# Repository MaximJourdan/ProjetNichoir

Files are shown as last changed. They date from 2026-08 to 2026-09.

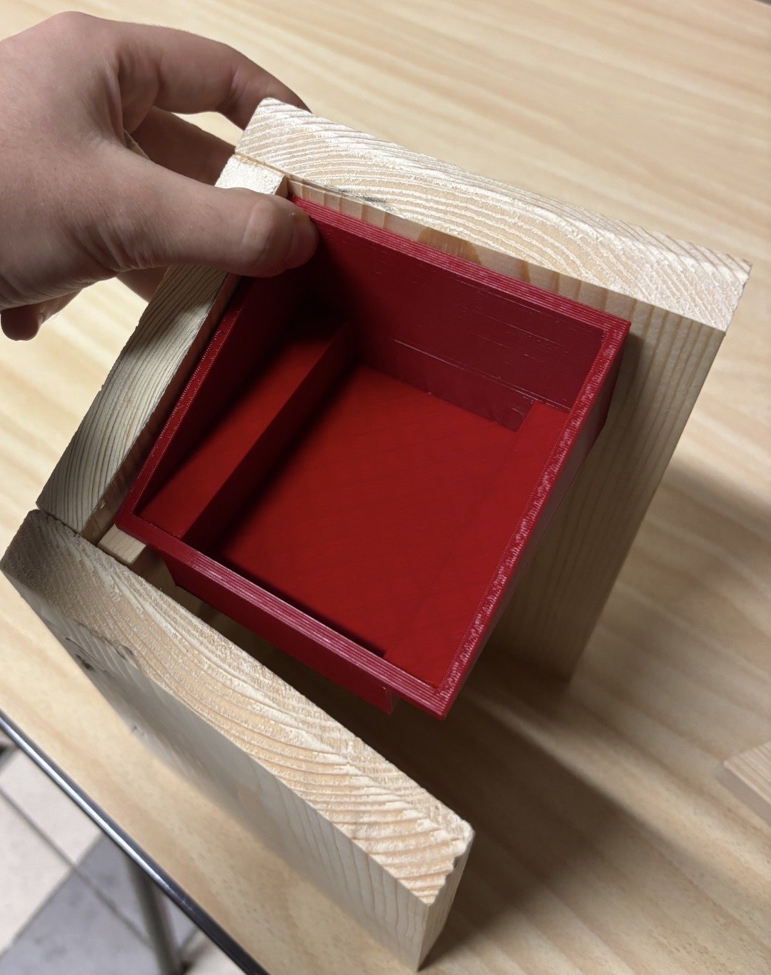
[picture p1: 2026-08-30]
ImagesEtSchemas/Nichoir4.jpg

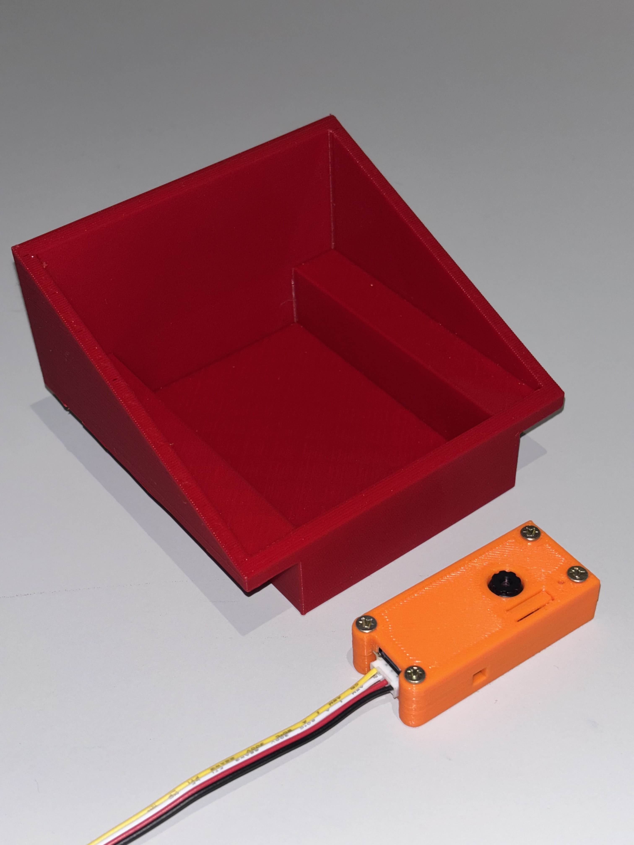
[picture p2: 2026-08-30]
ImagesEtSchemas/Nichoir2.jpg

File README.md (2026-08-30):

# 🐦 Nichoir Connecté – SmartCities 2025-2026

Projet étudiant développé à la **Haute École de la Province de Liège (HEPL)** dans le cadre du programme **Sciences de l’ingénieur industriel – orientation informatique**.

## 📌 Objectif
Créer un nichoir intelligent et connecté permettant de suivre la vie des oiseaux :
- Coût accessible (moins de 50 €)
- Autonomie énergétique prolongée (6 mois à 1 an sur batterie)
- Évolutif : ajout possible d’un panneau solaire

---

## 🔎 Analyse du marché
- Prix des solutions existantes : 130 – 300 €
- Alimentation : câble, panneaux solaires
- Stockage : carte SD, Wi-Fi cloud privé, RTSP
- Exemples : Green Backyard, Greenfeathers Bird Box Camera Kit

---

## ⚙️ Caractéristiques techniques
- **Microcontrôleur** : ESP32-DOWDQ6-V3  
- **Mémoire** : 8 MB PSRAM  
- **Caméra** : OV3660, 3MP, DFOV 66.5°, résolution max 2048x1536  
- **Indicateurs** : LED de statut + bouton RESET  
- **Gestion énergie** : RTC BM8563, consommation en veille ~2 µA, connecteur batterie externe  
- **Connectivité** : Wi-Fi, port USB debug, port HY2.0-4P pour périphériques externes  

Librairies utilisées : [TimerCam Arduino](https://github.com/m5stack/TimerCam-arduino/tree/master)

---

## 🔋 Gestion de l’énergie
- Mode **standby** : réveil quotidien pour envoi du niveau de batterie via MQTT  
- Mode **présence** : détection PIR → capture photo + envoi batterie associé  

---

## 📡 Fonctionnement du système
### Détection de mouvement
- Capteur PIR → déclenche capture photo avec éclairage IR

### Transmission des données
- Envoi des images au Raspberry Pi via Wi-Fi
- Script Python MQTT listener → stockage dans MariaDB
- Serveur Flask → galerie web + affichage des données

---

## 🛠️ Conception
- Breakout pour PIR, LED, TimerCam
- Package complet avec batterie/support piles
- Versioning et suivi sur GitHub

---

## ✅ Évaluation & Compétences
### C1 – Concevoir des systèmes complexes
- Architecture claire et modulaire
- Passage de la conception théorique à la réalisation pratique
- Optimisation en fonction des tests

### C2 – Mettre en œuvre des systèmes complexes
- Fiabilité et traçabilité des tests
- Documentation et reproductibilité
- Respect du cahier des charges

### C3 – Développer sa professionnalité
- Auto-formation et apprentissage continu
- Initiative et autonomie dans la recherche de solutions

---

## 🚀 Installation & Utilisation
### Prérequis
- ESP32 TimerCam
- Raspberry Pi avec Python 3
- MariaDB/MySQL
- Flask

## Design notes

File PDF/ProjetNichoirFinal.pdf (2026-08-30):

# Projet Nichoir

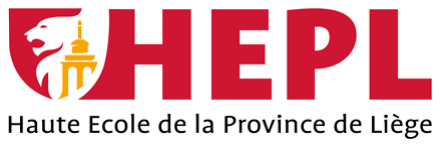
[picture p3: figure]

Travail Réalisé par Jourdan Maxim et Monthe Modeste

Année 2025-2026 Passerelle Électronique M13P

Introduction | 4
Cahier des Charges | 4
Objectifs généraux | 4
Exigences fonctionnelles | 5
Schéma | 5
Serveur MQTT Raspberry PI | 6
Pourquoi le protocole MQTT | 6
Mise en place du serveur MQTT sur Raspberry Pi | 6
Organisation des échanges MQTT | 6
Transmission des images par fragmentation | 6
Application Flask | 7
Architecture de l’application | 7
Fonctionnement général | 7
Interface Web | 8
Extensibilité du système | 8
M5 STACK Esp32 Camera | 8
Accès Wi-Fi et point d’accès de configuration | 9
Détection de mouvement et déclenchement des captures | 9
Transmission des données vers le serveur | 10
Gestion de l’énergie et modes de veille | 10
Capteur Infrarouge PIR | 10
Principe de fonctionnement | 10
Description des connexions du module PIR | 11
GND (Ground) | 12
3.3 V (Alimentation) | 12
Photoresist (Entrée photorésistance) | 12
Potentiomètre de sensibilité (Pot Sensi) | 12
Potentiomètre de temporisation (Pot Time) | 12
OUT (Sortie numérique) | 13
Board 5v PIR | 13
Schéma | 14
Alimentation et conversion de tension | 14
Conditionnement du capteur PIR | 15
Intégration de la LED d’éclairage | 15
Interface avec le module ESP32 TimerCAM | 16
Intérêt de la board dédiée | 16

Dessin 3D | 16
Étapes de conception et apprentissage | 17
Logiciel utilisé et méthodologie | 18
Fonctionnalité et sécurité thermique | 19
Résultat | 19
Tests | 19
Test du capteur PIR | 20
Transmission des images via MQTT | 20
Autonomie énergétique | 20
Limites | 20
Réveil depuis le mode veille du PIR | 20
Transmission réseau dépendante de la stabilité Wi-Fi | 21
Autonomie réelle vs autonomie théorique | 21
Exposition aux éléments | 21
Conclusion | 21
Perspectives | 22
Intégration d’un réseau LoRa Mesh | 22
Alimentation solaire | 22
Optimisation du mode veille | 22
Extension des fonctionnalités | 23
Scalabilité et modularité | 23

## Introduction

Le développement des villes intelligentes SmartCities s’accompagne d’un intérêt croissant pour le suivi de l’environnement urbain et de la biodiversité. La faune, et en particulier les oiseaux, constitue un indicateur pertinent de la qualité écologique des milieux urbains. Le suivi de leur comportement et de leur présence permet d’apporter des informations utiles tant pour la recherche scientifique que pour la sensibilisation du public à la préservation de l’environnement.

Dans ce contexte, le projet de nichoir connecté, réalisé dans le cadre du cours de passerelle Smart Cities, s’inscrit dans une démarche de conception d’un système IoT autonome, communicant et à faible consommation énergétique. L’objectif principal est de concevoir un nichoir intelligent capable de détecter la présence d’oiseaux, de capturer des images de manière non-intrusive et de transmettre ces données vers une infrastructure distante pour leur stockage et leur visualisation.

Le projet vise à proposer une solution économiquement accessible, avec un coût de fabrication inférieur aux solutions existantes du marché, tout en garantissant une autonomie énergétique prolongée grâce à l’utilisation d’une batterie et à une gestion optimisée de la consommation. L’ensemble du système repose sur un microcontrôleur embarqué intégrant une caméra, un capteur de mouvement infrarouge passif (PIR), ainsi qu’une communication Wi-Fi vers un serveur distant basé sur un Raspberry Pi.

Ce rapport présente l’ensemble des étapes de conception, de réalisation et de validation du nichoir connecté. Il aborde successivement l’architecture globale du système, les choix technologiques, la gestion de l’énergie, l’infrastructure de communication et de traitement des données, ainsi que les tests réalisés. Enfin, les limites du système actuel et les perspectives d’amélioration sont discutées.

## Cahier des Charges

## Objectifs généraux

Le système doit permettre :
La surveillance de l’activité à l’intérieur d’un nichoir à l’aide d’un système de détection de mouvement.
La capture d’images lors de la détection d’une présence.
La transmission des données vers un serveur distant pour stockage et visualisation.

Une autonomie énergétique prolongée, compatible avec une utilisation sur plusieurs mois sans intervention humaine.
Un coût global réduit, adapté à une solution pédagogique et déployable à grande échelle.

## Exigences fonctionnelles

Système embarqué:
Utilisation d’un module M5Stack ESP32 Camera (TimerCam).
Détection de mouvement à l’aide d’un capteur infrarouge passif (PIR).
Capture d’images déclenchée par le capteur PIR.
Éclairage infrarouge (LED IR) lors de la prise de vue afin de limiter l’impact sur les oiseaux.
Gestion des modes veille (sleep) afin de réduire la consommation énergétique.

Connectivité:
Mise en place d’un point d’accès Wi-Fi permettant la configuration initiale du réseau. Connexion automatique au réseau Wi-Fi configuré.
Transmission des images et des données via le protocole MQTT.

## Schéma

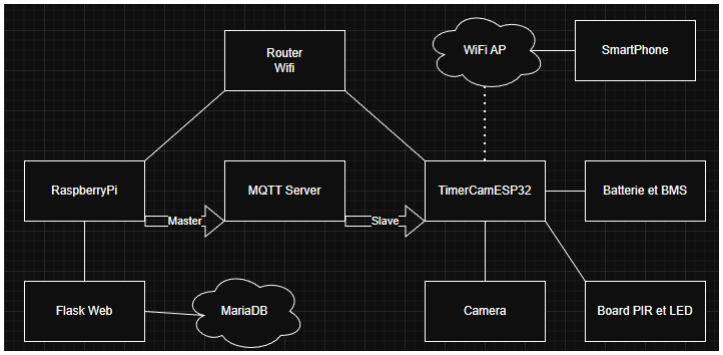
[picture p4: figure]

## Serveur MQTT Raspberry PI

## Pourquoi le protocole MQTT

Le protocole MQTT (Message Queuing Telemetry Transport) a été retenu pour sa légèreté et sa faible consommation réseau, adaptées aux systèmes IoT alimentés sur batterie. Son modèle publish/subscribe permet une communication asynchrone efficace, contrairement à HTTP, plus coûteux en ressources. MQTT facilite également l’évolutivité du système, plusieurs services pouvant exploiter les mêmes données sans modifier le module embarqué.

## Mise en place du serveur MQTT sur Raspberry Pi

Un Raspberry Pi est utilisé comme serveur central hébergeant le broker MQTT Mosquitto. Il assure la réception des images et des métadonnées envoyées par l’ESP32, ainsi que leur redistribution vers les services applicatifs. La configuration du broker permet la réception de messages volumineux nécessaires à la transmission des images.

## Organisation des échanges MQTT

Les échanges sont structurés à l’aide de topics MQTT distincts, séparant les images, les métadonnées (horodatage, niveau de batterie) et les informations de diagnostic. Cette organisation facilite le traitement et l’exploitation des données par le serveur applicatif.

## Transmission des images par fragmentation

Les images étant trop volumineuses pour un envoi unique, elles sont fragmentées en plusieurs blocs transmis successivement via MQTT. Un message de fin permet la reconstitution de l’image côté serveur, garantissant une transmission fiable tout en respectant les contraintes du protocole.

Dans une version future du système, des mécanismes de sécurisation des échanges MQTT (authentification, chiffrement TLS) pourraient être intégrés afin d’améliorer la protection des données transmises.

L’ensemble des scripts et commandes est disponible sur le dépôt GitHub du projet.

## Application Flask

Afin de permettre la visualisation des données collectées par le nichoir connecté, une application Web a été développée à l’aide du framework Flask, exécutée sur le Raspberry Pi. Flask a été choisi pour sa légèreté, sa simplicité d’intégration avec Python et sa pertinence dans des projets IoT de petite à moyenne échelle.

L’application Flask joue le rôle d’interface entre la base de données et l’utilisateur final. Elle permet de consulter les images capturées par le module ESP32 TimerCAM ainsi que les métadonnées associées, telles que la date de capture et le niveau de batterie du système embarqué.

## Architecture de l’application

L’application Web est intégrée dans un script unifié exécuté sur le Raspberry Pi, combinant :
- un listener MQTT chargé de recevoir les images et les métadonnées,
- une base de données MariaDB assurant le stockage persistant,
- un serveur Web Flask permettant l’affichage et l’accès aux données.

Cette architecture permet un fonctionnement continu et autonome du système, tout en limitant le nombre de services à gérer sur le Raspberry Pi.

## Fonctionnement général

Lorsqu’une image est reçue via le protocole MQTT, celle-ci est sauvegardée sur le système de fichiers du Raspberry Pi. Le chemin de l’image ainsi que les informations associées sont ensuite enregistrés dans la base de données. L’application Flask interroge cette base afin de récupérer l’ensemble des captures disponibles et de les présenter à l’utilisateur via une interface Web.

La page principale de l’application affiche une galerie d’images, organisée par ordre chronologique inverse. Chaque capture est accompagnée de métadonnées permettant d’évaluer l’état du système au moment de la prise de vue, notamment le niveau de batterie.

## Interface Web

L’interface Web a été conçue afin d’être claire, responsive et facilement exploitable sur différents supports. Elle propose :
- une galerie d’images issue des captures du nichoir,
- des indicateurs synthétiques tels que le nombre total de captures et le niveau de batterie moyen,
- une mise en forme facilitant l’analyse visuelle des données collectées.
Un mécanisme de rafraîchissement périodique permet d’actualiser automatiquement l’affichage, assurant ainsi la consultation des nouvelles images sans intervention manuelle.

## Extensibilité du système

En complément de l’interface graphique, l’application Flask expose des routes dédiées permettant d’accéder aux données sous forme structurée. Cette approche rend le système évolutif et compatible avec de futures extensions, telles que l’intégration d’outils d’analyse, de supervision ou de visualisation avancée.

Ainsi, l’application Flask constitue un élément central du projet, transformant le Raspberry Pi en un serveur Web complet, capable de valoriser les données issues du nichoir connecté de manière efficace et accessible.

## M5 STACK Esp32 Camera

Le système embarqué du nichoir repose sur un module M5Stack ESP32 TimerCAM, intégrant un microcontrôleur ESP32, une caméra et une gestion native de l’alimentation sur batterie. Ce module a été choisi pour sa compacité, sa faible consommation énergétique et sa capacité à combiner acquisition d’images et connectivité Wi-Fi au sein d’un même dispositif.

L’ESP32 TimerCAM constitue le cœur du système IoT. Il assure la détection d’événements à l’intérieur du nichoir, la capture des images, ainsi que leur transmission vers le serveur distant hébergé sur Raspberry Pi.

## Accès Wi-Fi et point d’accès de configuration

Afin de faciliter le déploiement du nichoir dans différents environnements, un
mécanisme de configuration réseau dynamique a été mis en place. Lors du premier démarrage, ou en l’absence de réseau connu, le module ESP32 crée automatiquement un point d’accès Wi-Fi dédié.

Ce point d’accès permet à l’utilisateur de se connecter au module et de configurer les identifiants du réseau Wi-Fi local sans avoir à modifier le code embarqué. Une fois les paramètres enregistrés, l’ESP32 se connecte automatiquement au réseau configuré lors des démarrages suivants.

Cette approche améliore la flexibilité du système et rend son installation accessible, même sans compétences avancées en programmation embarquée.

## Détection de mouvement et déclenchement des captures

La détection de présence à l’intérieur du nichoir est réalisée à l’aide d’un capteur infrarouge passif (PIR). Lorsqu’un mouvement est détecté, le capteur déclenche une séquence d’actions automatisées.

Dans un premier temps, une LED est activée afin d’éclairer brièvement la scène, garantissant une qualité d’image suffisante même dans des conditions de faible luminosité. La caméra capture ensuite une image de l’intérieur du nichoir.

Une fois la capture effectuée, l’image est immédiatement préparée pour être transmise vers le serveur distant. Ce fonctionnement événementiel permet de limiter les captures inutiles et de réduire la consommation énergétique globale du système.

En complément, des captures périodiques sont également réalisées à intervalles réguliers afin d’assurer un suivi continu de l’activité, même en l’absence de détection de mouvement.

## Transmission des données vers le serveur

Après chaque capture, l’image ainsi que les métadonnées associées (horodatage, niveau de batterie, identifiant du dispositif) sont envoyées via le réseau Wi-Fi en utilisant le protocole MQTT.

En raison des contraintes mémoire du microcontrôleur et de la taille des images, celles-ci sont fragmentées en plusieurs blocs avant d’être transmises. Le serveur reconstitue ensuite l’image complète à la réception de l’ensemble des fragments. Cette méthode garantit une transmission fiable tout en respectant les limitations matérielles de l’ESP32.

## Gestion de l’énergie et modes de veille

L’autonomie énergétique constitue un enjeu majeur du projet. Le module ESP32 TimerCAM fonctionne sur batterie et intègre plusieurs mécanismes visant à réduire sa consommation.

Des phases de mise en veille sont utilisées entre les captures afin de limiter l’activité du microcontrôleur. Des tests ont été réalisés avec différents modes de veille, notamment le deep sleep, afin d’évaluer leur compatibilité avec la détection de mouvement via le capteur PIR.

Ces expérimentations ont mis en évidence certaines limitations, notamment la difficulté de réveiller de manière fiable le système depuis un état de veille profonde à l’aide du capteur PIR. Ces contraintes ont conduit à des compromis entre autonomie énergétique et fiabilité de la détection, qui sont discutés plus en détail dans la section dédiée aux limites du système.

## Capteur Infrarouge PIR

## Principe de fonctionnement

Le capteur infrarouge passif (PIR – Passive Infrared Sensor) est utilisé pour détecter la présence ou le mouvement d’un corps chaud dans son champ de vision. Il fonctionne en mesurant les variations du rayonnement infrarouge émis naturellement par les objets, et en particulier par les êtres vivants.

Le capteur PIR ne génère pas de rayonnement ; il se contente de détecter les variations d’énergie infrarouge reçues. Lorsqu’un oiseau entre dans le nichoir ou se déplace à proximité du capteur, la variation thermique est détectée et convertie en un signal électrique exploitable par le microcontrôleur.

Ce type de capteur présente plusieurs avantages pour un système autonome :
- faible consommation énergétique
- fonctionnement simple
- absence d’émission active, donc non-intrusif pour les animaux

Ces caractéristiques en font un choix particulièrement adapté au projet de nichoir connecté.

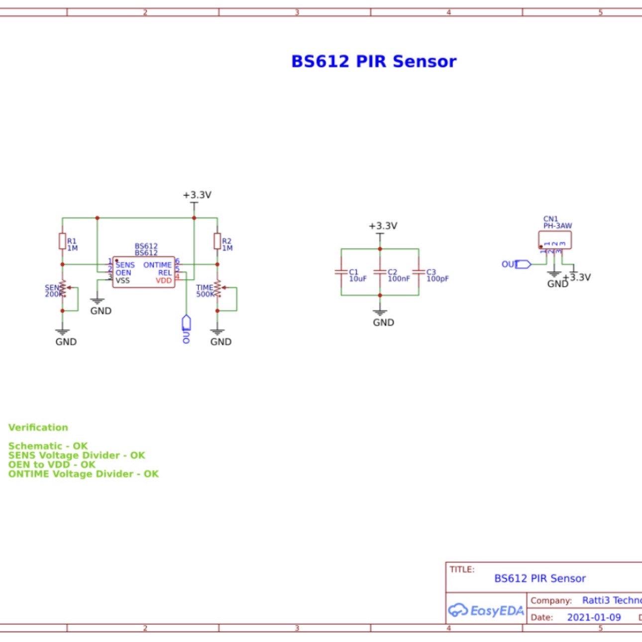
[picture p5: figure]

## Description des connexions du module PIR

Le module PIR utilisé dans ce projet dispose de six connexions, permettant d’alimenter le capteur, de régler son comportement et de récupérer le signal de détection.

GND (Ground)
La broche GND correspond à la masse du circuit. Elle est reliée à la masse commune du système afin d’assurer une référence électrique stable entre le capteur PIR et le microcontrôleur ESP32.

### 3.3 V (Alimentation)

La broche 3.3 V permet d’alimenter le module PIR. Dans ce projet, le capteur est alimenté par la tension fournie par le système embarqué. L’utilisation d’une tension compatible avec l’ESP32 évite l’ajout de composants de conversion supplémentaires.

Photoresist (Entrée photorésistance)
La broche photoresist est associée à une photorésistance intégrée au module. Elle permet d’adapter le comportement du capteur en fonction de la luminosité ambiante.

Cette entrée peut être utilisée pour inhiber la détection lorsque la lumière est suffisante, ou au contraire pour privilégier les détections en conditions de faible luminosité. Dans le cadre du projet, cette fonctionnalité a été identifiée comme une possibilité d’amélioration, mais n’a pas été exploitée pleinement.

Potentiomètre de sensibilité (Pot Sensi)
Le potentiomètre de sensibilité permet de régler la distance ou l’amplitude de détection du capteur PIR. Un réglage élevé augmente la portée du capteur, tandis qu’un réglage plus faible limite la zone de détection.

Ce paramètre est important afin d’éviter les déclenchements intempestifs causés par des mouvements extérieurs au nichoir, tels que le vent ou des variations thermiques non pertinentes.

Potentiomètre de temporisation (Pot Time)
Le potentiomètre de temporisation définit la durée pendant laquelle la sortie du capteur reste à l’état actif après une détection. Il permet de contrôler le temps durant lequel le signal de sortie reste à l’état “haut”.

Ce réglage est utilisé pour adapter la durée de déclenchement à l’application, par exemple afin de laisser suffisamment de temps au système pour capturer et transmettre une image avant un retour à l’état de veille.

OUT (Sortie numérique)
La broche OUT est la sortie logique du capteur PIR. Elle passe à l’état “haut” lorsqu’un mouvement est détecté et revient à l’état “bas” après la durée définie par le potentiomètre de temporisation.

Cette sortie est directement reliée à une entrée numérique de l’ESP32, permettant de déclencher les actions logicielles : activation de la LED, capture d’image et transmission des données.

## Board 5v PIR

Afin d’adapter le capteur PIR et la LED d’éclairage aux contraintes d’alimentation du système embarqué, une carte électronique dédiée a été conçue et réalisée. Cette board intermédiaire permet de centraliser l’alimentation, le conditionnement des signaux et l’interface avec le module ESP32 TimerCAM.

L’objectif principal de cette carte est de fournir une alimentation stable au capteur PIR en 3,3 V, tout en exploitant une alimentation principale en 5 V, et de simplifier les connexions vers le système embarqué.

## Schéma

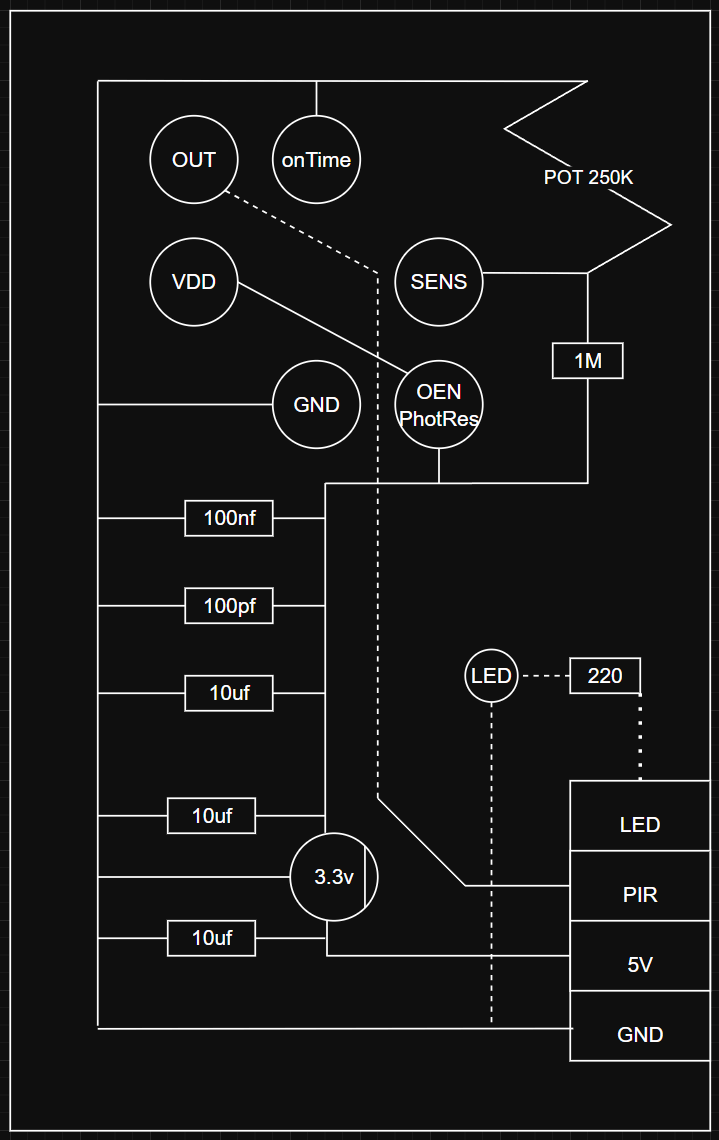
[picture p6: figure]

## Alimentation et conversion de tension

Le système est alimenté en 5 V, notamment pour la LED d’éclairage. Cependant, le capteur PIR fonctionne de manière optimale sous 3,3 V, tension compatible avec les entrées de l’ESP32.

Un régulateur de tension 5 V → 3,3 V est intégré sur la board afin d’assurer une alimentation stable du capteur PIR. Ce régulateur est accompagné de deux condensateurs de découplage de 10 µF, placés respectivement à l’entrée et à la sortie du régulateur, afin de :

- lisser les variations de tension,
- améliorer la stabilité du régulateur,
- réduire le bruit électrique.

## Conditionnement du capteur PIR

Le capteur PIR utilisé nécessite un ajustement de sa sensibilité afin d’être adapté à l’environnement restreint du nichoir. Pour cela, un réseau de composants passifs a été ajouté sur la board.

Un potentiomètre de 200 kΩ et une résistance de 1 MΩ sont utilisés pour former un pont diviseur, permettant d’ajuster finement la sensibilité du capteur. Ce réglage est essentiel pour éviter les déclenchements intempestifs causés par des variations thermiques non pertinentes.

Afin de garantir une alimentation propre et stable du capteur PIR, trois condensateurs ont été ajoutés sur la ligne 3,3 V :
10 µF pour le filtrage basse fréquence,
100 nF pour le découplage classique,
100 pF pour la suppression des parasites haute fréquence.

Cette combinaison permet d’assurer un fonctionnement fiable du capteur, même dans un environnement soumis à des perturbations électriques.

## Intégration de la LED d’éclairage

La board intègre également la gestion de la LED utilisée pour l’éclairage lors de la capture d’image. La LED est alimentée directement en 5 V et associée à une résistance de limitation de courant, dimensionnée afin de protéger la LED et d’assurer une luminosité suffisante sans surconsommation.

L’activation de la LED est commandée par le microcontrôleur, permettant de synchroniser précisément l’éclairage avec la prise de vue, tout en minimisant la durée d’activation afin de réduire l’impact énergétique et lumineux sur les oiseaux.

## Interface avec le module ESP32 TimerCAM

La board a été conçue pour communiquer simplement avec le module ESP32 TimerCAM à l’aide de quatre fils :
GND : masse commune du système,
5 V : alimentation principale,
LED_IN : commande de la LED,
PIR_OUT : signal de détection du capteur PIR.

Ces signaux sont reliés au connecteur du module ESP32 utilisant l’interface I²C (SCL / SDA) disponible sur le TimerCAM. Cette approche permet une intégration propre et compacte, sans modification matérielle du module principal.

## Intérêt de la board dédiée

La réalisation de cette board 5 V PIR présente plusieurs avantages :
- séparation claire entre alimentation, détection et commande,
- amélioration de la fiabilité du capteur PIR,
- réduction du câblage direct vers l’ESP32,
- facilité de maintenance et d’évolution du système.

Cette approche modulaire s’inscrit pleinement dans une démarche de conception adaptée à un projet IoT autonome destiné à fonctionner sur de longues périodes sans intervention.

## Dessin 3D

La conception du boîtier du nichoir a été réalisée afin de protéger le module ESP32 TimerCAM, le capteur PIR, la LED et la batterie, tout en s’intégrant facilement dans le nichoir et en assurant une bonne aération. L’objectif principal était de créer un boîtier pratique, spacieux, fonctionnel et compatible avec l’impression 3D.

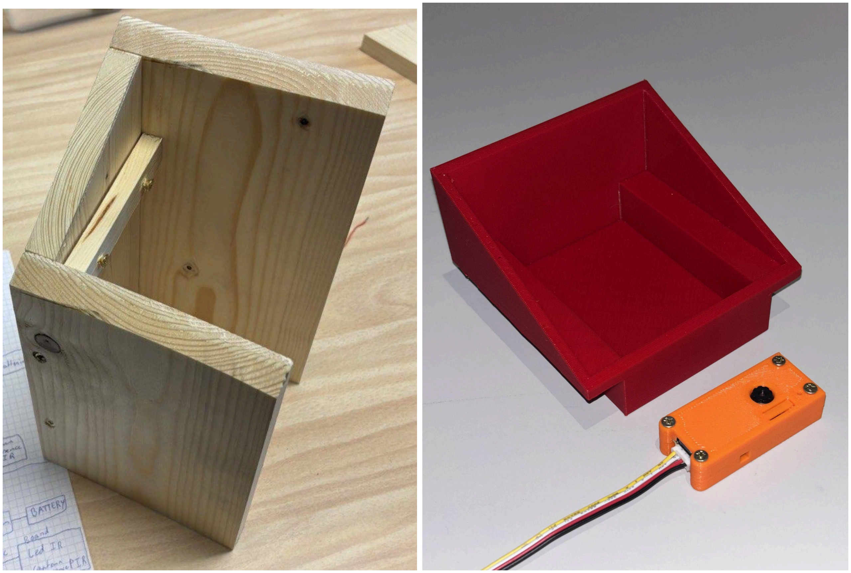
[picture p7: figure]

## Étapes de conception et apprentissage

La conception a débuté par la création d’un boîtier hyper compact, destiné uniquement au module ESP32 TimerCAM. Cinq versions d’impression ont été réalisées pour tester la taille, l’ergonomie et la protection du module pendant le développement. Ces essais ont permis d’apprendre plusieurs notions importantes de l’impression 3D, notamment :
- comment ajouter des murs, rainures et plots pour maintenir les composants correctement en place,
- comment éviter que des objets ne se touchent ou ne se chevauchent dans l’espace 3D,
- comment concevoir des ouvertures pour les fils et les boutons tout en conservant l’étanchéité relative et la protection contre la poussière.

Cette expérience initiale a été très utile pour ensuite créer un boîtier plus grand et complet, capable d’accueillir l’ensemble du système (ESP32, PIR, LED, batterie).

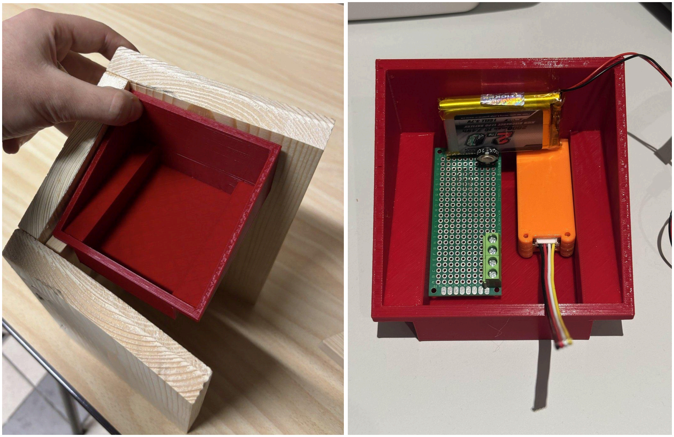
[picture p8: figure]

## Logiciel utilisé et méthodologie

Le logiciel Fusion 360 a été utilisé pour concevoir le boîtier. La méthodologie suivie a été la suivante :

Sketch 2D : création de profils en deux dimensions correspondant aux faces du boîtier ou aux ouvertures pour les composants.

Extrusion en bloc 3D : transformation des sketches 2D en volumes solides, donnant naissance aux différentes parties du boîtier.

Fusion et assemblage des blocs : les différents volumes ont été combinés pour former l’architecture finale, en veillant à ce que chaque composant ait son espace dédié.

Ajout de détails fonctionnels :
- trous pour le passage des fils de batterie,
- encoches pour les boutons,
- ouvertures pour le capteur PIR et la LED,
- logement pour la caméra.

Cette approche modulaire a permis de gérer efficacement l’espace et de garantir la facilité de montage et de maintenance.

## Fonctionnalité et sécurité thermique

Le boîtier final offre une protection complète tout en permettant une aération suffisante : les trous pour les fils et les boutons contribuent à l’évacuation de la chaleur, et la température à l’intérieur du boîtier reste dans des limites sûres pour le fonctionnement du module ESP32.

Malgré ces ouvertures, le boîtier reste étanche une fois en position dans le nichoir, protégeant les composants de l’humidité et de la poussière. Le câblage à l’intérieur est organisé de manière compacte et sécurisée, sans risque de court-circuit ou de tension excessive sur les fils.

## Résultat

Le boîtier 3D final :
- protège tous les composants,
- laisse suffisamment de place pour la batterie,
- facilite le montage et le démontage,
- assure une aération adaptée tout en restant étanche,
- est esthétique et adapté à l’environnement du nichoir.

Cette étape a constitué un apprentissage concret de la modélisation 3D et de l’impression, notamment pour passer d’une idée en 2D à un boîtier fonctionnel en 3D, ce qui est une compétence clé pour tout projet IoT embarqué nécessitant un boîtier spécifique.

## Tests

Plusieurs tests ont été réalisés afin de valider le bon fonctionnement du système du nichoir connecté.

## Test du capteur PIR

Le capteur PIR a été vérifié pour détecter correctement la présence d’oiseaux dans le nichoir. Des ajustements ont été effectués sur le potentiomètre de sensibilité pour limiter les déclenchements intempestifs dus aux mouvements extérieurs ou aux variations thermiques. Le réglage de la temporisation (Pot Time) a été testé pour s’assurer que la LED IR et la capture de l’image disposent du temps nécessaire avant que le signal ne repasse à l’état “bas”.

## Transmission des images via MQTT

Le protocole MQTT a été testé en envoyant plusieurs images vers le serveur Raspberry Pi. La reconstruction des images fragmentées a été vérifiée et validée. Des tests de robustesse réseau ont également été réalisés, avec interruption volontaire de la connexion, pour observer la reprise et la fiabilité des transmissions.

## Autonomie énergétique

L’autonomie du système a été estimée en fonction de son fonctionnement actuel, avec un ESP32 partiellement alimenté pour le PIR. Une comparaison théorique a été faite avec le mode veille complet du vrai M5Stack Sleep, qui éteint totalement l’ESP32. Ces tests ont permis de mesurer l’impact des phases de veille, de la consommation de la LED et du PIR sur la durée de fonctionnement de la batterie.

Les résultats ont montré que le système remplit son rôle, tout en soulignant les limites liées à la gestion de l’énergie et aux interruptions réseau.

## Limites

Malgré les résultats encourageants obtenus lors des tests, certaines limites du système ont été identifiées :

## Réveil depuis le mode veille du PIR

Le principal point faible concerne le réveil de l’ESP32 depuis le vrai mode sleep profond fourni par le M5Stack. Le capteur PIR n’arrive pas à déclencher le réveil lorsque le microcontrôleur est totalement éteint. Cela limite l’autonomie maximale du système, car il faut rester dans un mode veille partiel pour garantir la détection de mouvement.

## Transmission réseau dépendante de la stabilité Wi-Fi

La fiabilité des envois d’images via MQTT dépend fortement de la qualité du réseau Wi-Fi. En cas de coupure ou de faible signal, certaines images peuvent être retardées ou nécessiter une retransmission.

## Autonomie réelle vs autonomie théorique

L’autonomie estimée avec le mode veille partiel est inférieure à celle qui serait obtenue avec le vrai M5Stack sleep. Cela implique qu’une batterie plus grande ou une optimisation logicielle serait nécessaire pour une autonomie prolongée sur plusieurs mois sans intervention.

## Exposition aux éléments

Même si le boîtier reste étanche dans sa position finale, il est soumis aux variations de température et d’humidité. Des tests supplémentaires seraient nécessaires pour valider un usage long terme en extérieur

## Conclusion

Le projet nichoir connecté a atteint son objectif principal : créer un système autonome capable de détecter la présence d’oiseaux, de capturer des images et de les transmettre vers un serveur distant.

Les tests ont montré que le capteur PIR fonctionne correctement, que la synchronisation avec la LED et la caméra est efficace, et que la transmission via MQTT permet de récupérer les images et les métadonnées dans de bonnes conditions. Le boîtier 3D conçu protège l’ensemble des composants tout en assurant une aération suffisante et un câblage sécurisé.

Le système est opérationnel et démontre la faisabilité d’un nichoir connecté à faible coût et à autonomie optimisée. Malgré certaines contraintes techniques, notamment liées au mode sleep complet de l’ESP32, le projet a permis d’acquérir des compétences concrètes en IoT, impression 3D, électronique et réseau.

En résumé, l’objectif de conception et de démonstration d’un nichoir intelligent fonctionnel est atteint, et le système peut servir de base pour des améliorations futures et des expérimentations supplémentaires.

## Perspectives

Le nichoir connecté offre déjà un prototype fonctionnel, mais plusieurs axes d’amélioration peuvent être envisagés pour augmenter l’autonomie, la portée et la robustesse du système:

## Intégration d’un réseau LoRa Mesh

L’utilisation de la technologie LoRa en mesh permettrait d’étendre la portée du nichoir et de créer un réseau de plusieurs dispositifs communicants. Grâce à cette approche, plusieurs nichoirs pourraient partager leur position et leurs données en temps réel, même dans des zones où le Wi-Fi n’est pas disponible. Cette méthode est inspirée de projets précédents réalisés avec un T-Beam LoRa GPS, démontrant la faisabilité d’un réseau décentralisé et autonome.

## Alimentation solaire

L’ajout d’un petit panneau solaire permettrait de recharger la batterie du nichoir et d’assurer une autonomie prolongée, réduisant ainsi la nécessité d’interventions humaines. Combiné à une gestion optimisée de l’énergie et à des modes de veille efficaces, le système pourrait fonctionner plusieurs mois voire années de manière autonome.

## Optimisation du mode veille

L’étude d’un deep sleep plus performant, éventuellement compatible avec le réveil par le PIR ou par un timer, pourrait améliorer considérablement l’autonomie tout en conservant une détection fiable des mouvements.

## Extension des fonctionnalités

D’autres capteurs environnementaux (température, humidité, luminosité) pourraient être intégrés pour enrichir les données collectées et permettre une analyse plus complète du comportement des oiseaux et des conditions du nichoir.

## Scalabilité et modularité

Grâce à l’architecture modulaire du boîtier et de l’électronique, il est possible de reproduire le système pour plusieurs nichoirs et de centraliser les données sur un serveur unique ou un cloud, facilitant les expérimentations à plus grande échelle.

Ces perspectives montrent que le projet peut évoluer vers un véritable système IoT de suivi écologique, combinant autonomie énergétique, communication longue portée et modularité, tout en conservant un coût accessible et une approche pédagogique.

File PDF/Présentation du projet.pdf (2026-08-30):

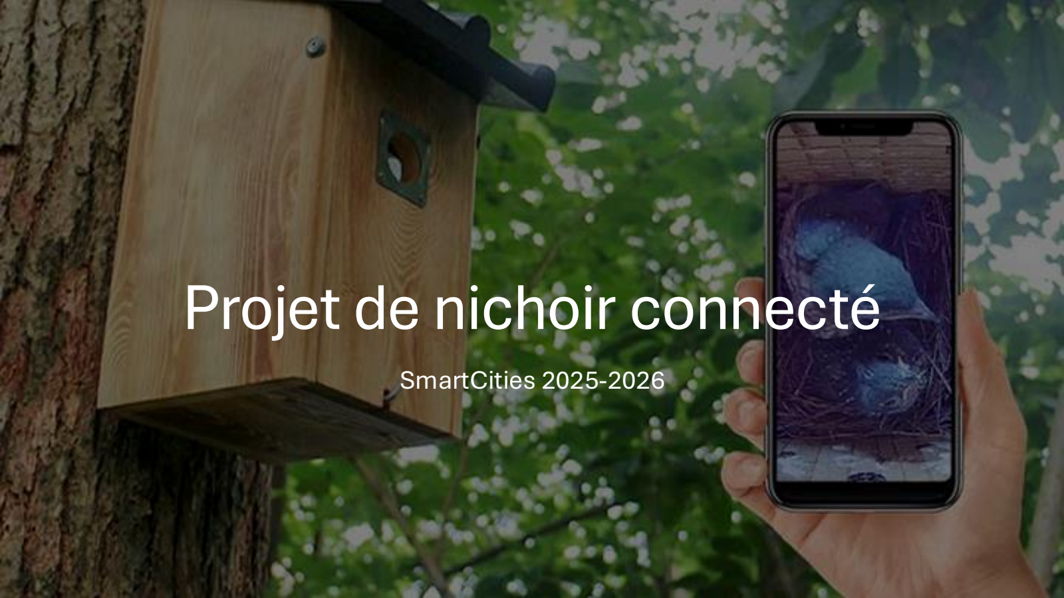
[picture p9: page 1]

# Projet de nichoir connecté

## SmartCities 2025-2026

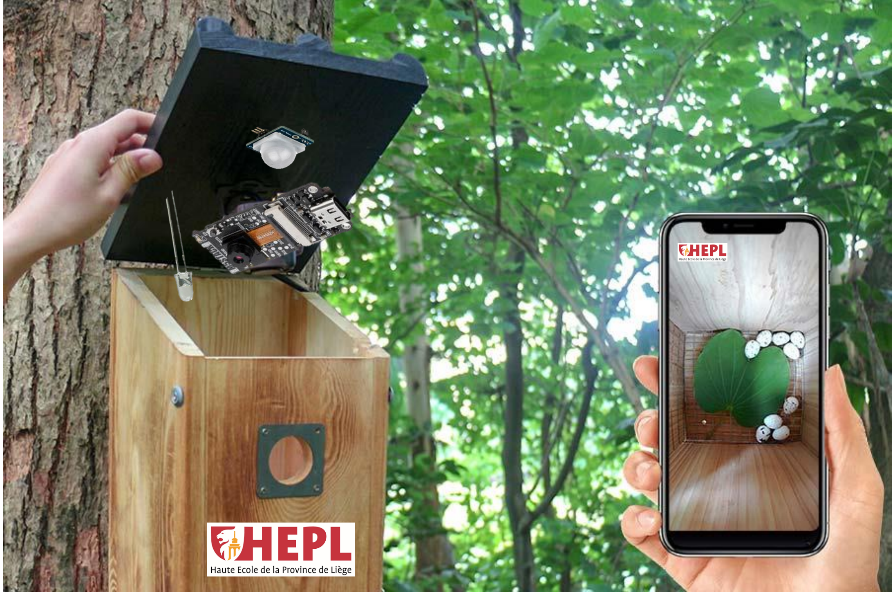
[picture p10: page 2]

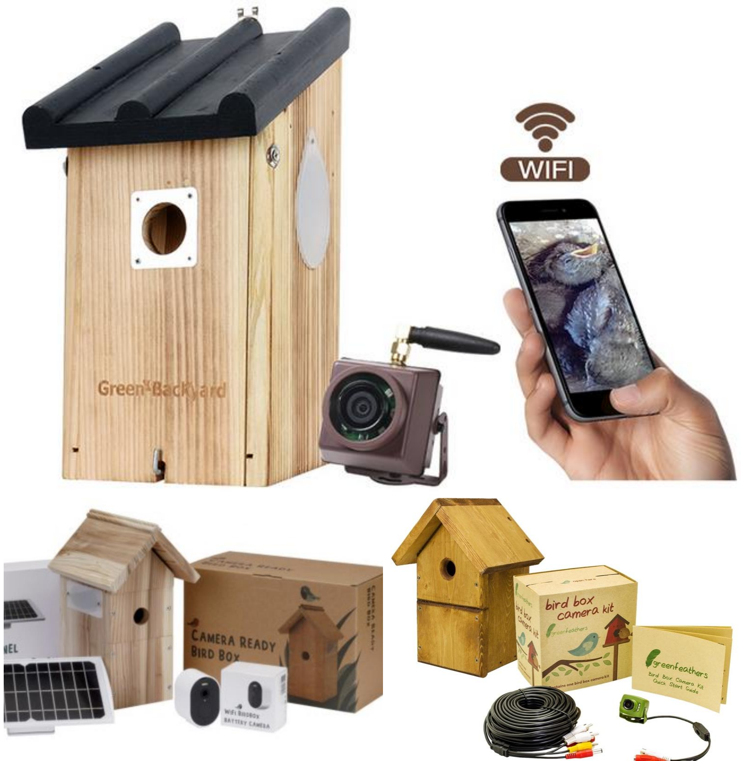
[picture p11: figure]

# Analyse du marché

## - Prix : 130 – 300 € - Alimentation : Câblé, panneaux solaires

- Stockage : Carte SD, câblé, connexion WiFi cloud (privé),

## RSTP …

# Nichoir Connecté - Proposition de Valeur

Objectif :
Créer un nichoir intelligent et connecté qui permet de suivre la vie des oiseaux avec un coût accessible et une autonomie énergétique prolongée.

Caractéristiques principales :

- Prix : Moins de 50 €
- Autonomie énergétique : 6 mois à 1 an sur batterie
- Évolutif : Possibilité d'ajouter un panneau solaire pour augmenter l'autonomie

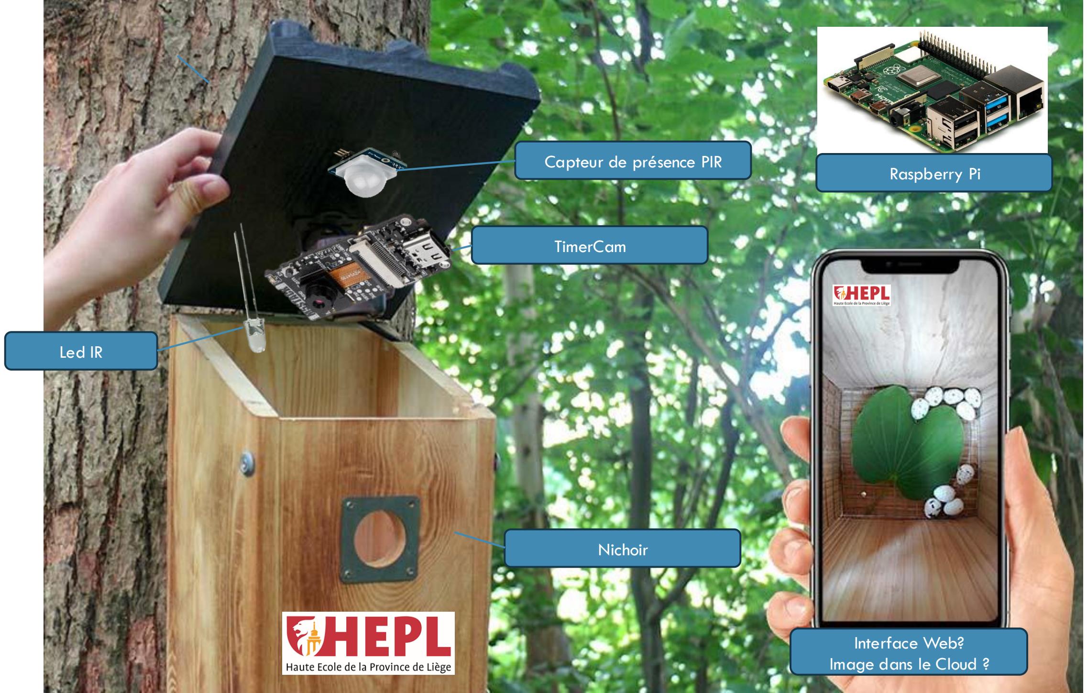
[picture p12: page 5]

Capteur de présence PIR

TimerCam

Led IR

Raspberry Pi

Interface Web?
Image dans le Cloud ?

Nichoir

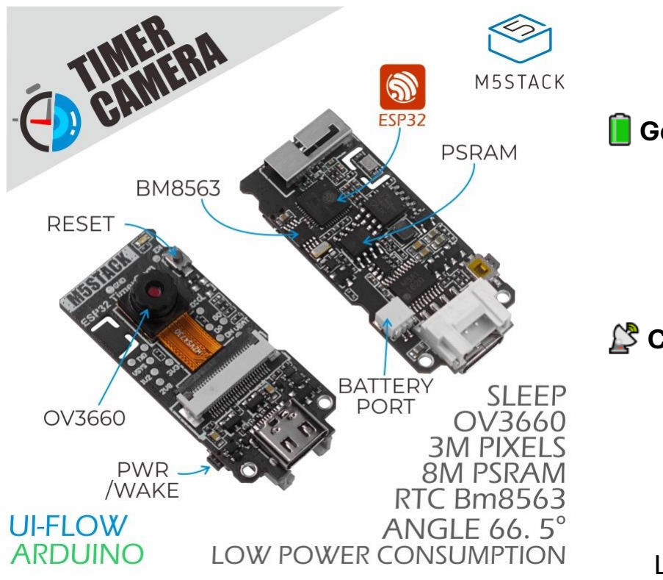
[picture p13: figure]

Librairies :
https://github.com/m5stack/TimerCam-arduino/tree/master (https://github.com/m5stack/TimerCam-arduino/tree/master)

Composants et caractéristiques techniques
- Microcontrôleur : ESP32-D0WDQ6-V3
- Mémoire : 8MB PSRAM
- Caméra : OV3660, 3MP, DFOV 66.5°, résolution jusqu’à 2048x1536
- Indicateurs : LED de statut + bouton RESET
Gestion de l’énergie
- Conception ultra-basse consommation
- RTC intégré (BM8563) pour réveil et mise en veille programmés
- Courant en veille : aussi bas que 2μA
- Connecteur batterie réservé pour alimentation externe Connectivité et communication
- Transmission d’image via Wi-Fi
- Port USB pour débogage
- Port HY2.0-4P pour connecter des périphériques externes

MQTT

Objectifs

- Surveiller l'activité dans un nichoir via un système de détection de mouvement et de capture d'images.
- Diminuer la consommation pour une autonomie utile pour l’application.
- Publier les données avec une mise en page.

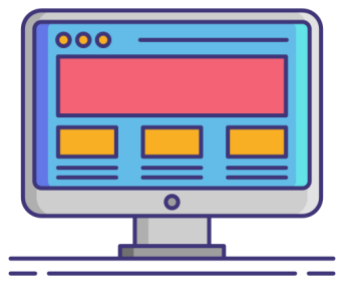
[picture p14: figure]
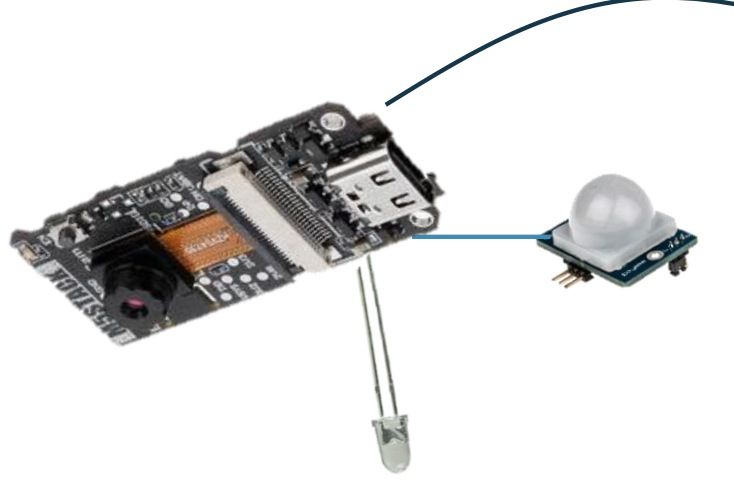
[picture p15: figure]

Galerie

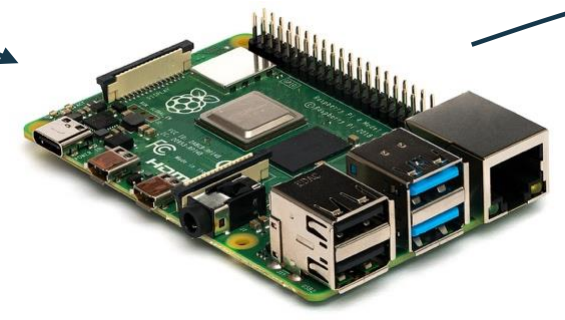
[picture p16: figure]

### Fonctionnement du système

- Accès AP + interface Web

Configuration :

- Un capteur PIR détecte la présence d'oiseaux dans le nichoir.
- Lorsqu'un mouvement est détecté, le TimerCAM capture une photo avec un éclairage IR.

Détection de mouvement :

- La photo est envoyée au Raspberry Pi via Wi-Fi pour traitement et stockage en MQTT.
- Un script python sur le Raspberry Pi reçoit les images et données via MQTT et le stocke dans une base de données MySQL (MariaDB)
- Un second script Python sur le Raspberry Pi permettra de créer un serveur WEB (Flask) qui affichera une galerie d'images et les données dans un format adéquat

Transmission des données :

- Mode standby : En absence de mouvement dans le nichoir, le système se réveille une fois par jour et envoie le niveau de la batterie en MQTT.
- Mode Présence : Lorsque le capteur PIR détecte un mouvement, le niveau de la batterie est associé à chaque photo capturée.

Niveau de la batterie :

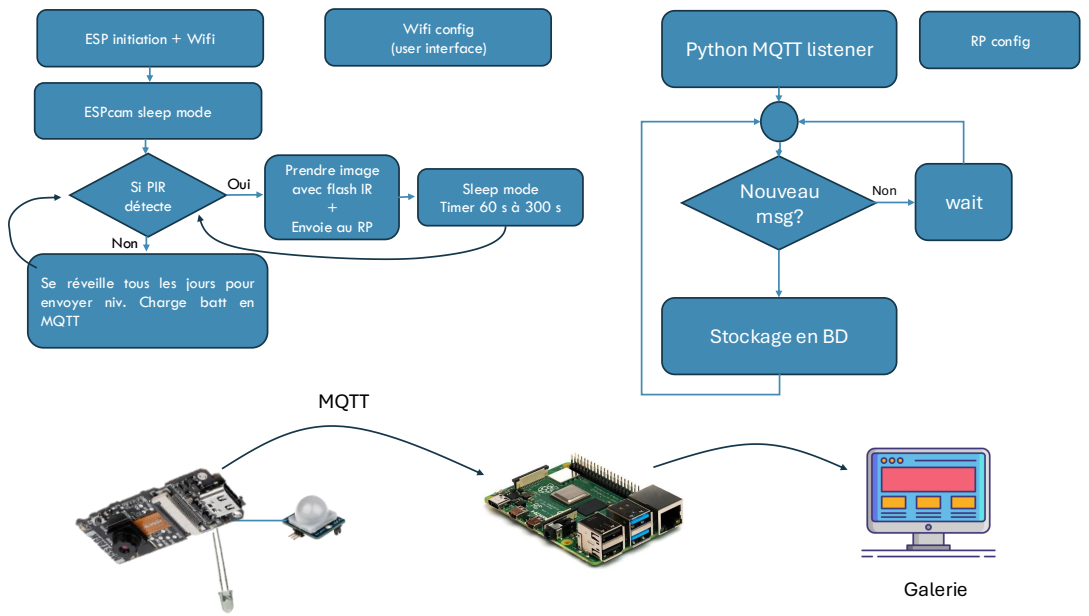
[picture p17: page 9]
Si PIR détecte; Sleep mode Timer 60 s à 300 s; Wifi config; (user interface); RP config; Oui; Non; MQTT; Galerie; Nouveau; msg?; wait

ESP initiation + Wifi

Python MQTT listener

ESPcam sleep mode

Prendre image
avec flash IR
Envoie au RP

Se réveille tous les jours pour
envoyer niv. Charge batt en
MQTT

Stockage en BD

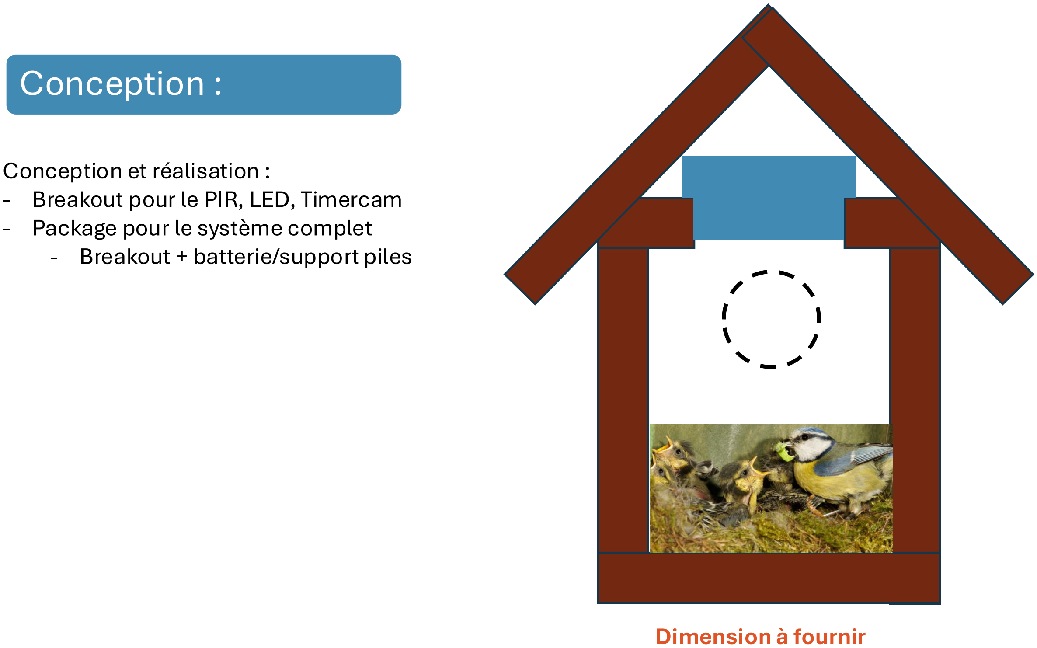
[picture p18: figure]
Conception :; Conception et réalisation : - Breakout pour le PIR, LED, Timercam - Package pour le système complet - Breakout + batterie/support piles; Dimension à fournir

Evaluation

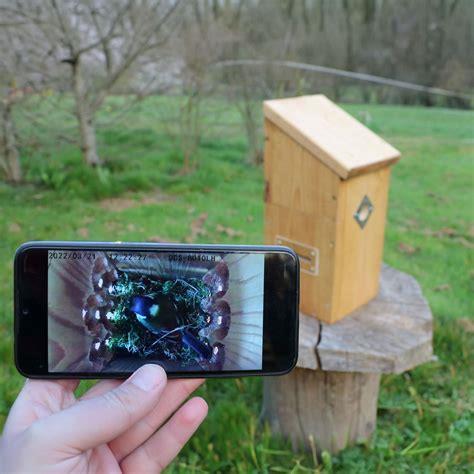
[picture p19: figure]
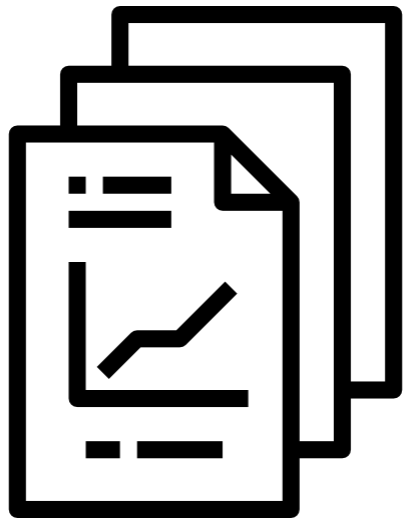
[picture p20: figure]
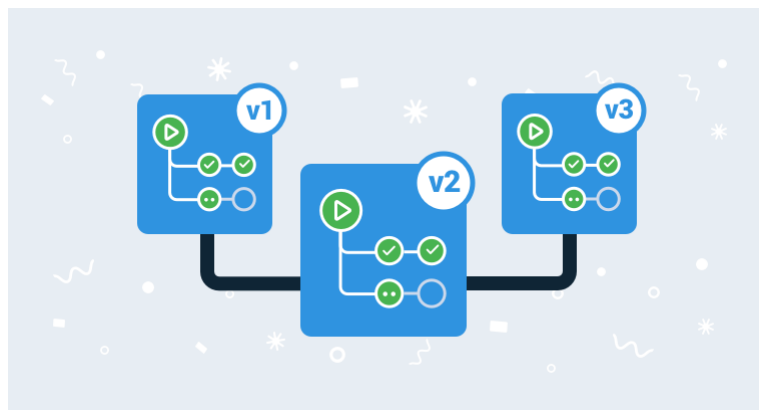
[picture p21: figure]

Prototype | Rapport | Versioning sur Github

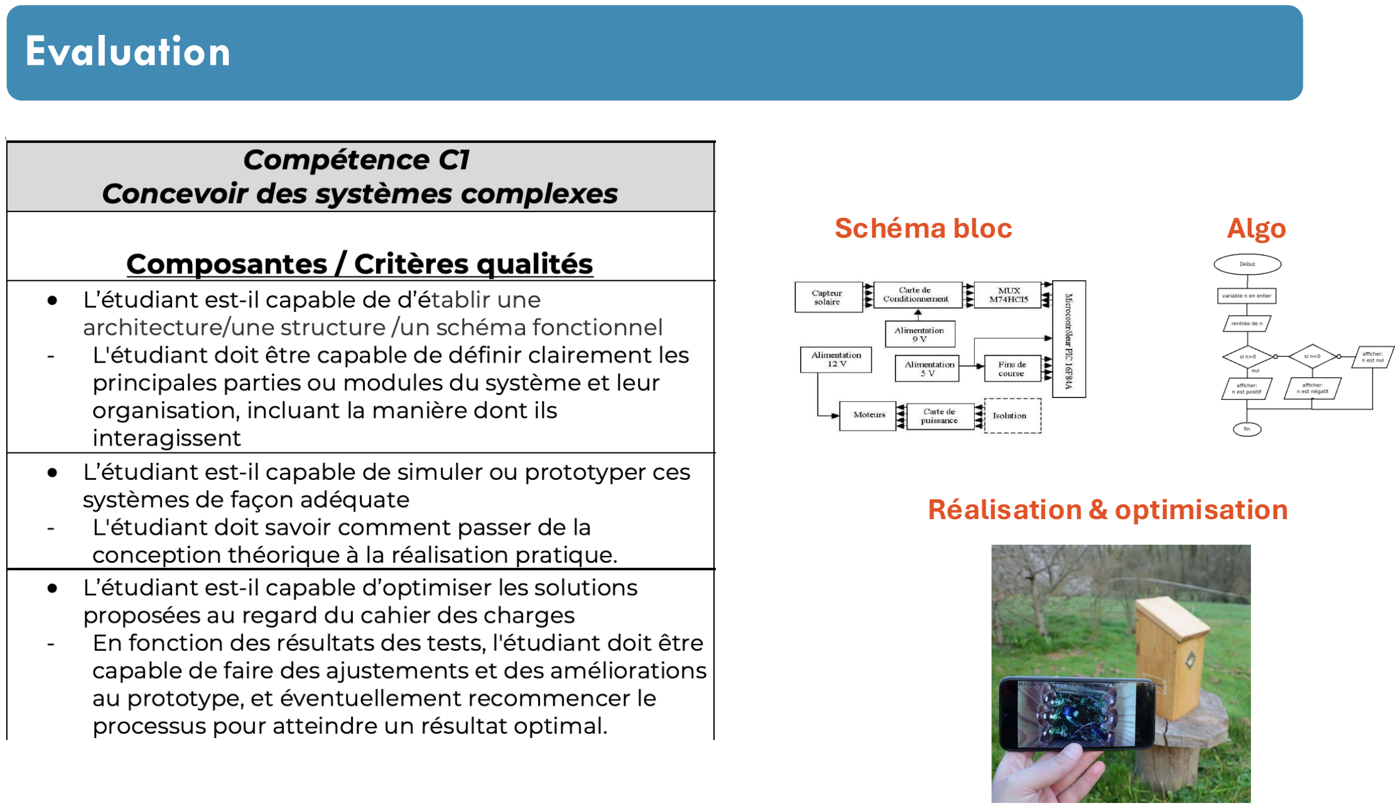
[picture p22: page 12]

Schéma bloc

Réalisation & optimisation

Algo

Evaluation

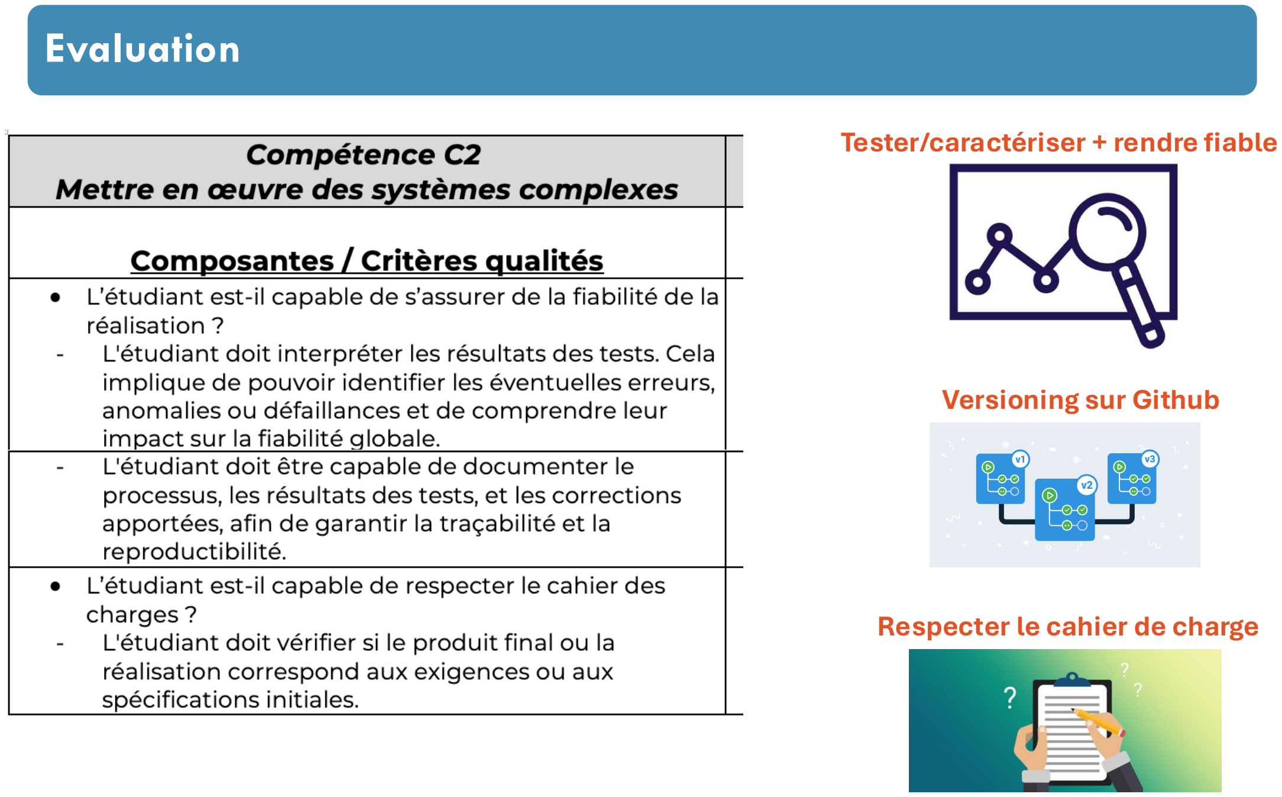
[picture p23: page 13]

Tester/caractériser + rendre fiable

Versioning sur Github

Respecter le cahier de charge

Evaluation

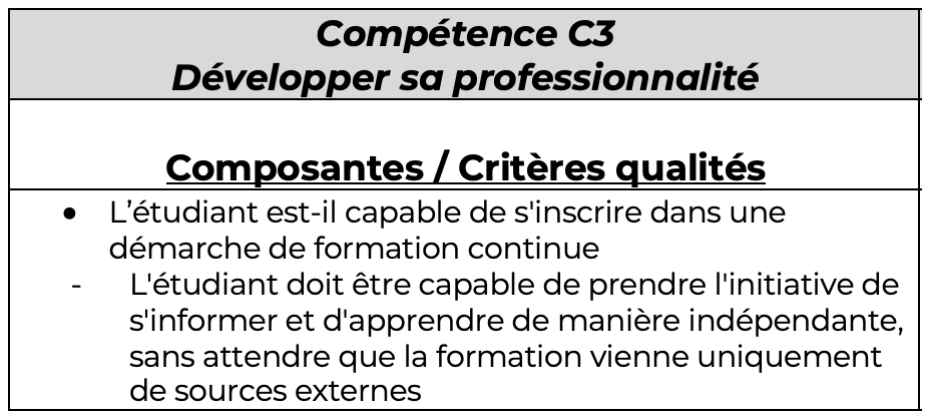
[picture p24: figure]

Auto-formation

Evaluation

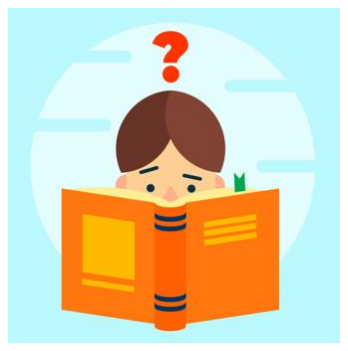
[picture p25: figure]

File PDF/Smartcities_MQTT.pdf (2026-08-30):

# Le protocole MQTT

De Dijcker Sebastien
Haute Ecole de la Province de Liège – Catégorie Technique

# 1. Introduction

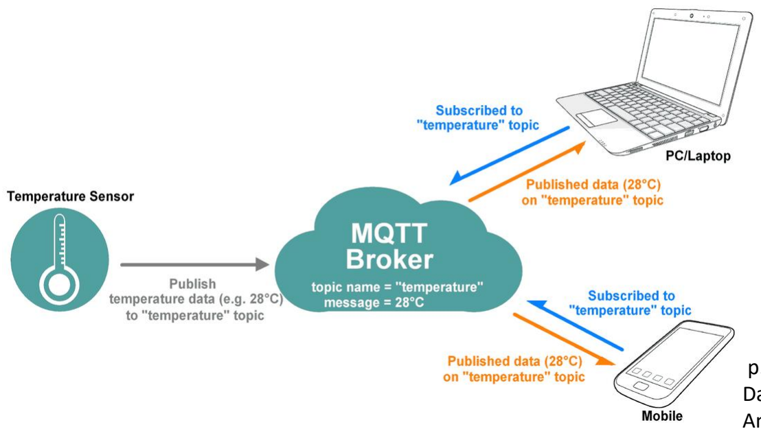
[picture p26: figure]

p.ex.: MQTT
Dashboard sur
Android

# 1.1 Définition

- Message Queuing Telemetry Transport
- Protocole de transport de type Client/Serveur
- Pattern d’échange de message de type subscribe/publish:
- Le client publie des message sur un topic vers le serveur,
- Le client s’abonne à des topics, et reçoit les messages du serveur concernant ce topic.
- Utilisé pour l’IoT (Internet of Things) et le M2M (Machine to Machine)
- Standard OASIS (Organization for the advancement of Structured Information Standards)

# 1.2 Fonctionnalités principales

- Nécessite peu de code et est facile à implémenter
- Utilise le protocole TCP/IP
- Quantité de données transmises réduites au maximum
→Idéal quand il y a peu de ressources mémoires, une bande passante ou un débit limité
- Mécanisme de QoS (Quality of Service)

### - Possibilité de stocker les messages publiés au niveau du broker - Securité: possibilité d’authentification par username/password

# 1.3 Applications

- Domotique
- Automobile
- Automation industrielle
- Soins de santé
- Applications mobiles (messagerie, monitoring)
- IoT en général

# 2. Le protocole

# 2.1 Control packet

- Pour fonctionner, MQTT échange une série de paquets de contrôle chacun composés de maximum trois parties:

Fixed Header – Présent dans tous les paquets de contrôle Variable Header – Présent dans certains paquets de contrôle Payload – Présentes dans certains paquets de contrôle

# 2.1.1 Control Packet – Fixed Header

Bit | 7 | 6 | 5 | 4 | 3 | 2 | 1 | 0
Byte 1 | Type | | | | Flags (type dependant)
Byte 2 | Remaining length
- Type :
- 1 – CONNECT : Demande de connexion
- 2 – CONNACK : ACK de connexion
- 3 – PUBLISH : Publier un message
- 4 – PUBACK : ACK de message (QoS1)
- 5 – PUBREC : Publication reçue (QoS2)
- 6 – PUBREL : Publication publiée (QoS2)
- 7 – PUBCOMP : Publication complète (QoS2)

# 2.1.1 Control Packet – Fixed Header

Bit | 7 | 6 | 5 | 4 | 3 | 2 | 1 | 0
Byte 1 | Type | | | | Flags (type dependant)
Byte 2 | Remaining length
- Type :
- 8 – SUBSCRIBE : S’abonner à un topic
- 9 – SUBACK : ACK d’abonnement
- 10 – UNSUBSCRIBE : Se désabonner d’un topic
- 11 – UNSUBACK : ACK de désabonnement
- 12 – PINGREQ : Requête PING
- 13 – PINGRESP : Réponse PING
- 14 – DISCONNECT : Notification de déconnexion
- 15 – AUTH : Echange d’authentification

# 3. Les Topics

# 3. Topics

- Les topics sont des identificateurs textuels permettant de différencier la source ainsi que la nature des données
- Les topics peuvent être choisis arbitrairement et sont dépendants de l’application
- On peut créer une arborescence de topics grâce au symbole ‘/’
- Exemples: home/1stFloor/temperature/bedroom home/1stFloor/temperature/bathroom home/gndFloor/temperature/bedroom
- Attention, Les topics sont sensibles à la casse

# 3.1 Les Wildcards

- Il existe deux Wildcards
- La dièse (#) peut représenter plusieurs niveaux dans la hiérarchie de topics(topic parent ainsi que tous les enfants). Il doit toujours être le dernier caractère.
- Exemple: Si un client s’abonne à ‘home/1stFloor/temperature/#’, il recevra les messages publiés sur les topics suivants:
- ‘home/1stFloor/temperature’
- ‘home/1stFloor/temperature/bedroom’
- ‘home/1stFloor/temperature/bathroom’

# 4.1 Les Wildcards

- Il existe deux Wildcards
- Le plus (+) peut représenter un seul niveaux dans la hiérarchie de topics.
- Exemple: Si un client s’abonne à ‘home/+/temperature/bedroom’, il recevra les messages publiés sur les topics suivants:
- ‘home/1stFloor/temperature/bedroom’
- ‘home/gndFloor/temperature/bedroom’
- Exemple 2 : Si un client s’abonne à ‘home/+’, il recevra les messages publiés sur les topics suivants:
- ‘home/1stFloor’
- ‘home/gndFloor’

# 4. Mosquitto

An open source MQTT Broker

# 4. Mosquitto

- Mosquitto est un logiciel open source permettant de déployer simplement un broker MQTT ainsi qu’un client MQTT
- Disponible pour Windows, Linux, Debian, Raspberry, …

# 4.1 Mosquitto sur Raspberry

- Sur Raspberry, Mosquitto est disponible dans les repository principal. Dès lors, pour l’installer il suffit de lancer les commandes suivantes:
- Mosquitto se lance au démarrage du Raspberry.
- Le fichier de configuration se trouve dans /etc/mosquitto/
- Un exemple de fichier de configuration complet se trouve dans /usr/share/doc/mosquitto/examples (gunzip mosquitto.conf.gz) seb@retropie:~ $ sudo apt-get update seb@retropie:~ $ sudo apt-get upgrade seb@retropie:~ $ sudo apt-get install mosquitto seb@retropie:~ $ sudo apt-get install mosquitto-clients

# 4.1 Mosquitto sur Raspberry

- Afin de tester si Mosquitto fonctionne correctement, il suffit de s’abonner à un topic dans un terminal (mosquitto_sub):
- Options:
- -h pour spécifier l’hote (ip, localhost,…)
- -t pour spécifier le topic auquel on veut s’abonner (utilisez votre groupe dans le topic)
- -p pour spécifier le port (1883 par défaut, 1885 sur la carte Nyala) seb@retropie:~ $ mosquitto_sub –h localhost –t "home/1stFloor/temperature/bathroom" –p 1885

# 4.1 Mosquitto sur Raspberry

- Et d'envoyer un message sur ce même topic (mosquitto_pub)
- Options:
- -h pour spécifier l’hote (ip, localhost,…)
- -t pour spécifier le topic auquel on veut s’abonner
- -p pour spécifier le port (1883 par défaut, 1885 sur la carte Nyala)
- -m pour spécifier le message
- -u pour le nom d’utilisateur (pas nécessaire)
- -P pour son mot de passe (pas nécessaire)

seb@retropie:~ $ mosquitto_pub –h localhost –t "home/1stFloor/temperature/bathroom" –p 1885 –m "message de test"

# 5. Envoyer des messages depuis Python

- Il existe une libraire facilitant l'envoi/réception de messages vers un broker MQTT: la librairie PAHO
- Nous voyons une manière simple de l'utiliser dans un script Python:

import paho.mqtt.client
#création de l'objet client

monClientMqtt = paho.mqtt.client.Client() #connexion au serveur (adresse ip, port) monClientMqtt.connect("127.0.0.1",1885)
#envoi d'un message vers le serveur (topic, message) monClientMqtt.publish("testTopic","HelloWorld")

# 6. Exercice

- Tester le broker mosquitto avec mosquitto_pub et mosquitto_sub en ligne de commande
- Publier un message sur le broker depuis python, le réceptionner avec mosquitto_sub
- Envoyer la température du BME280 en boucle, toutes les 5 secondes, réceptionner avec mosquitto_sub
- Consigne générale: utiliser votre groupe (B11…B14) dans TOUS VOS TOPICS

# 7. Recevoir des messages MQTT depuis Python

- Après avoir envoyé des messages sur le broker MQTT, il serait idéal d'également pouvoir recevoir des messages depuis ce broker sur un certain topic.
- La librairie Paho offre plusieurs possibilités

# 7. Recevoir des messages MQTT depuis Python

- Le cas simple: on désire uniquement recevoir des messages.
- Il va falloir faire plusieurs choses:
- Souscrire au(x) topic(s) sur lesquels nous voulons recevoir des messages
- Définir une fonction qui sera appelée lors de la réception du message
- Faire le lien entre cette fonction qu'on a définie et la réception du message
- Attendre un message indéfiniment

# 7. Recevoir des messages MQTT depuis Python

- Le cas simple: on désire uniquement recevoir des messages.
- Il va falloir faire plusieurs choses:
- Souscrire au(x) topic(s) sur lesquels nous voulons recevoir des messages
- Définir une fonction qui sera appelée lors de la réception du message
- Faire le lien entre cette fonction qu'on a définie et la réception du message
- Attendre un message indéfiniment

Une fois la connexion avec le broker établie, nous pouvons souscrire à un topic grâce à la fonction subscribe:

monClientMqtt.subscribe("topicAuquelOnSAbonne")

# 7. Recevoir des messages MQTT depuis Python

- Le cas simple: on désire uniquement recevoir des messages.
- Il va falloir faire plusieurs choses:
- Souscrire au(x) topic(s) sur lesquels nous voulons recevoir des messages
- Définir une fonction qui sera appelée lors de la réception du message
- Faire le lien entre cette fonction qu'on a définie et la réception du message
- Attendre un message indéfiniment

Ce type de fonction est appelé une fonction de callback, voici comment elle doit être définie:

def nomDeMaFonctionDeCallback (client, userdata, msg):
#code de la fonction, par exemple print(msg.payload)

# 7. Recevoir des messages MQTT depuis Python

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

Ce type de fonction est appelé une fonction de callback, voici comment elle doit être définie:

def nomDeMaFonctionDeCallback (client, userdata, msg):
#code de la fonction, par exemple print(msg.payload)

msg est un objet de type
MQTTMessage, et contient les informations suivantes:
- topic
- payload
- qos
- retain
- mid (message id)
- properties

# 7. Recevoir des messages MQTT depuis Python

- Le cas simple: on désire uniquement recevoir des messages.
- Il va falloir faire plusieurs choses:
- Souscrire au(x) topic(s) sur lesquels nous voulons recevoir des messages
- Définir une fonction qui sera appelée lors de la réception du message
- Faire le lien entre cette fonction qu'on a définie et la réception du message
- Attendre un message indéfiniment Il faut préciser à notre connexion quelle fonction appeler lors de la réception

d'un message:

monClientMqtt.on_message = nomDeMaFonctionDeCallback

# 7. Recevoir des messages MQTT depuis Python

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

Une fois que tout est correctement configuré, nous pouvons entrer dans une boucle infinie en attente de messages grâce à la fonction:

monClientMqtt.loop_forever()

# 7. Recevoir des messages MQTT depuis Python

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

Une fois que tout est correctement configuré, nous pouvons entrer dans une boucle infinie en attente de messages grâce à la fonction:

monClientMqtt.loop_forever()

Mais quel est le problème dans ce cas?

# 7.1. Recevoir des messages MQTT depuis Python, mais aussi en envoyer

- Afin de régler le problème rencontré au slide précédent (on est dans une boucle infinie, donc impossible d'envoyer des messages), nous allons voir une autre fonction "loop" de la librairie Paho, également appelées sur l'objet Client (comme loop_forever)
- Il s'agit en réalité de deux fonctions:
- loop_start() : qui permet de démarrer une boucle d'attente, mais dans un "thread" séparé, en tâche de fond
- loop_stop() : qui met fin à la tâche de fond lancé au préalable
- Ainsi, entre l'appel à loop_start et loop_stop, nous pouvons mettre la logique de notre programme, durant laquelle nous pouvons envoyer des messages!

# 7.2. Parenthèse sur les variables

- A votre avis, que va afficher le code suivant:

maVariable = 5

def fctTest():
maVariable = 6
print(f"Dans la fonction: {maVariable}")

print(f"Avant appel: {maVariable}") fctTest()
print(f"Après appel: {maVariable}")

# 7.2. Parenthèse sur les variables

- A votre avis, que va afficher le code suivant:

maVariable = 5

def fctTest():
maVariable = 6
print(f"Dans la fonction: {maVariable}")

print(f"Avant appel: {maVariable}") fctTest()
print(f"Après appel: {maVariable}")

Résultat de l'exécution:
Avant appel: 5
Dans la fonction: 6
Après appel: 5

La variable "maVariable" dans la fonction n'existe que dans le corps de cette fonction, et n'a aucun lien avec la variable du programme principal!

Mais dès lors, comment pourrait-on modifier quoi que ce soit depuis une fonction de Callback? ➔ le mot clé global

# 7.2. Parenthèse sur les variables

- Dans une fonction, il est possible de préciser qu'une variable est globale à tout le script, et que ce que l'on modifie n'est pas une variable locale à la fonction, mais bien une variable globale. Le code devient alors:

maVariable = 5

def fctTest():
global maVariable
maVariable = 6
print(f"Dans la fonction: {maVariable}") print(f"Avant appel: {maVariable}") fctTest()
print(f"Après appel: {maVariable}")

# 7.3. Une callback par topic

- Dans la fonction appelée lors de la réception d'un message, nous pourrions distinguer les différents topics des différents messages à l'aide d'alternatives.
- Il existe cependant un méthode plus appropriée: assigner une fonction pour chaque topic:
- La fonction "on_message" sera appelée si le message reçu ne rentre dans aucune autre fonction

# 7.3. Une callback par topic: Exemple import paho.mqtt.client

def callbackTopicTempChambre(client, userdata, msg):
print(f"La temperature de la chambre est de {msg.payload}")

def callbackTopicTempBureau(client, userdata, msg): print(f"La temperature du bureau est de {msg.payload}")

def callbackParDefaut(client, userdata, msg):
print(f"Message recu sur le topic {msg.topic}: {msg.payload}")

monClientMqtt = paho.mqtt.client.Client() monClientMqtt.connect("192.168.1.130", 1883) monClientMqtt.subscribe("temp/#")

monClientMqtt.message_callback_add("temp/chambre",callbackTopicTempChambre) monClientMqtt.message_callback_add("temp/bureau",callbackTopicTempBureau) monClientMqtt.on_message = callbackParDefaut
monClientMqtt.loop_forever()

# 8. MQTT sur ESP32

- Libraire PubSubClient (Nick O’Leary)
- Voir exemples dans l’IDE Arduino

# Sources

- Protocole MQTT: OASIS – MQTT Version 5.0 – 07 March 2019: https://docs.oasis-open.org/mqtt/mqtt/v5.0/mqtt-v5.0.pdf
- Wiki MQTT: https://github.com/mqtt/mqtt.github.io/wiki
- Mosquitto: https://mosquitto.org/

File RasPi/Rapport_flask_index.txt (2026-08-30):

Voici un résumé clair, structuré de ma partie sur :
- la partie Flask du fichier app_unified.py
- la partie interface web avec index.html

🟦 Résumé – Partie Flask (app_unified.py)
La partie Flask de l'application joue le rôle de serveur web et d’interface entre la base de données et l’utilisateur. Elle est intégrée dans le script unifié qui combine :
- un listener MQTT (thread séparé)
- une API Flask
- un serveur web affichant les images du nichoir
🎯 Objectif de la partie Flask
Fournir une interface web moderne permettant :
- d’afficher les images capturées par l’ESP32 TimerCAM
- de consulter les métadonnées (batterie, date, mouvement)
- d’exposer des API REST pour d’autres services
🧱 Structure principale
La partie Flask contient :
✔ 1. Initialisation
- Création de l’application Flask
- Définition du dossier static/ pour les images
- Connexion à MariaDB via une fonction dédiée
✔ 2. Routes Web
/ – Page principale
- Récupère toutes les captures(path) dans la base de données
- Formate les dates et ajoute un champ “il y a X temps”
- Génère les URLs des images pour l’affichage
- Calcule des statistiques simples :
- nombre total de captures
- batterie moyenne
Cette route renvoie le template index.html.
/api/health
- Indique l’état du système :
- statut du MQTT
- statut de la base de données
- chemin des images
/api/captures
- Renvoie les 50 dernières captures en JSON
- Inclut :
- URL web
- date formatée
- “time_ago”
/api/stats
- Renvoie des statistiques globales :
- total d’images
- batterie moyenne
- dernière capture
- captures des dernières 24h
✔ 3. Gestion du temps
Fonction get_time_ago() qui convertit un timestamp en texte humain :
- “il y a X minutes”
- “il y a X heures”
- “il y a X jours”
✔ 4. Architecture
- Le listener MQTT tourne dans un thread séparé
- Flask tourne en parallèle sur le port 5000
- Les deux partagent la même base de données
👉 Conclusion :
La partie Flask transforme le Raspberry Pi en serveur web complet, capable d’afficher, d’analyser et d’exposer les données du nichoir.

🟩 Résumé – Partie HTML (index.html)
Ton fichier index.html constitue l’interface utilisateur du projet.
Il est moderne, responsive et très bien structuré.
🎨 Objectif
Afficher une galerie d’images capturées automatiquement par l’ESP32 TimerCAM, avec leurs métadonnées.
🧱 Structure du template
✔ 1. En-tête (Header)
- Titre du projet
- Sous-titre explicatif
- Icône (FontAwesome)
- Trois cartes statistiques :
- total des captures
- batterie moyenne
- statut du système
✔ 2. Galerie d’images
Pour chaque capture :
- vignette de l’image
- badge avec le device_id
- date complète
- niveau de batterie (couleur selon le pourcentage)
- indication “il y a X temps”
- icône “mouvement détecté” si applicable
✔ 3. Gestion des cas sans images
Une section “empty state” élégante :
- icône caméra barrée
- message explicatif
- trois icônes (WiFi, MQTT, caméra) pour guider le diagnostic
✔ 4. Footer
- rappel du projet HEPL
- description du système
- date de mise à jour
- adresse du serveur
✔ 5. JavaScript intégré
- animation d’apparition des cartes
- rafraîchissement automatique toutes les 2 minutes
- ajout dynamique de l’heure serveur
✔ 6. Style général
- utilisation de Google Fonts (Poppins)
- icônes FontAwesome
- design moderne, couleurs douces, cartes arrondies
👉 Conclusion :
index.html offre une interface professionnelle, claire et agréable, parfaitement adaptée au projet SmartCities

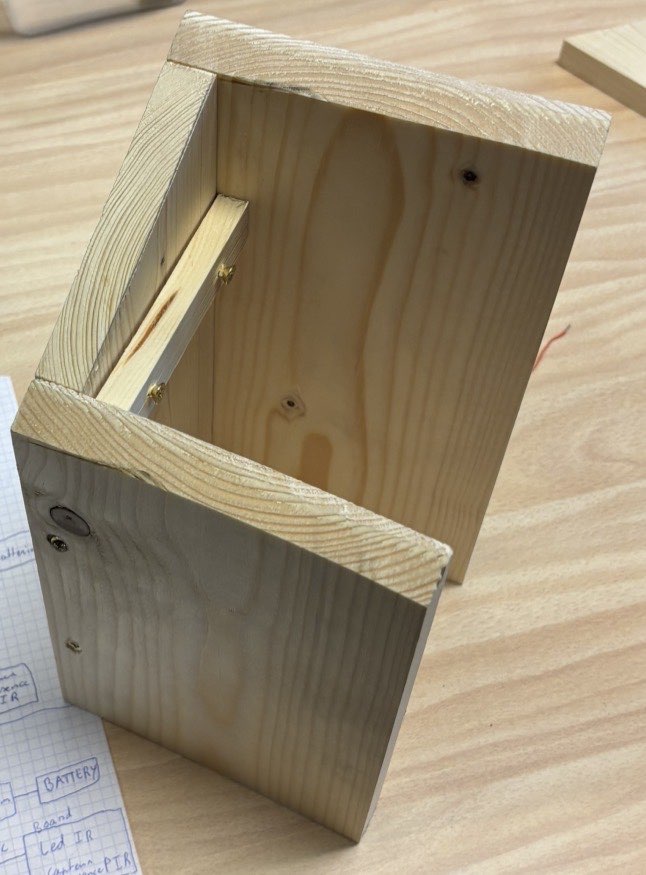
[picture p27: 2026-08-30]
ImagesEtSchemas/Nichoir3.jpg

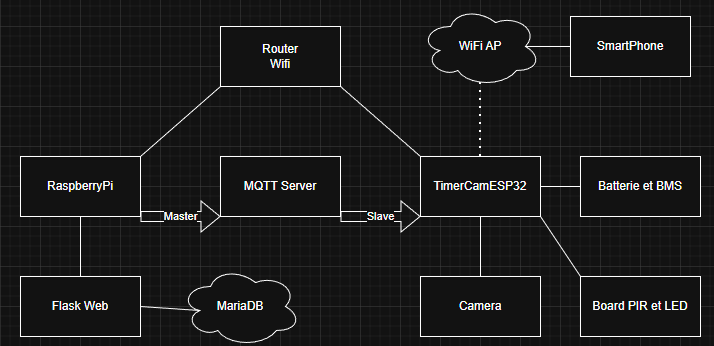
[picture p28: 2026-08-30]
ImagesEtSchemas/NichoirDiaGeneral.png

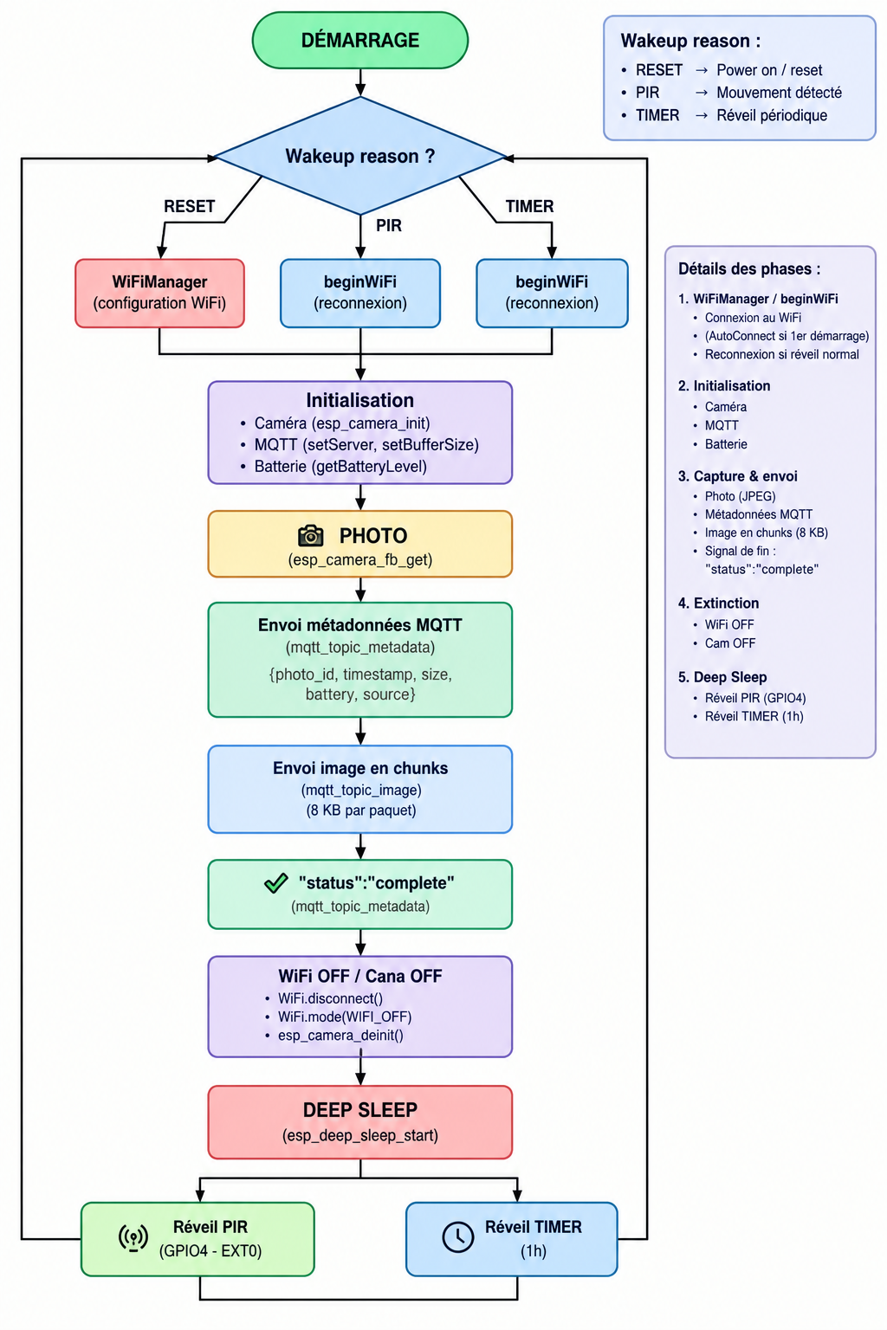
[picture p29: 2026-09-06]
TimerCamera/SchemaBlocTimerCam.png

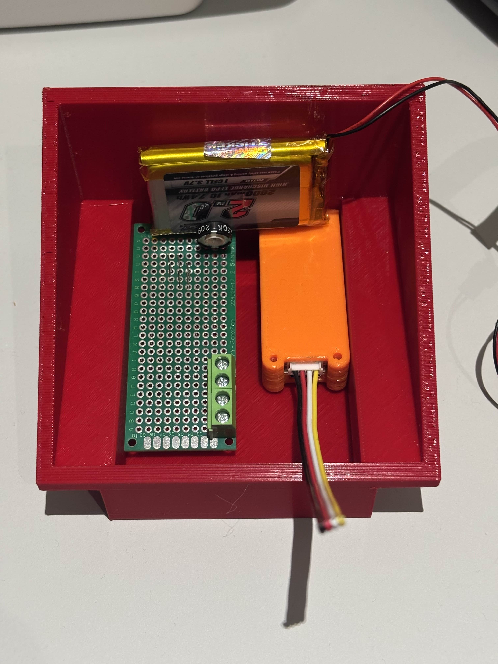
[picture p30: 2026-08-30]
ImagesEtSchemas/Nichoir.jpg

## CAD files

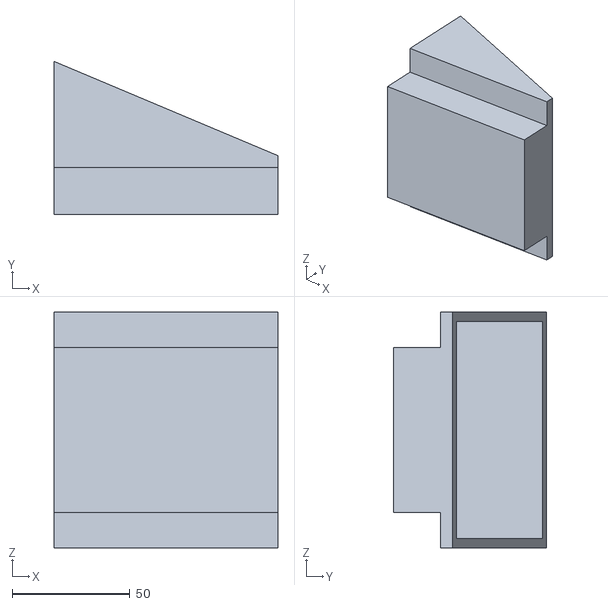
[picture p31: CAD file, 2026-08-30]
Plans3D/NichoirOiseauV2.stl
95.0 x 65.0 x 100.0

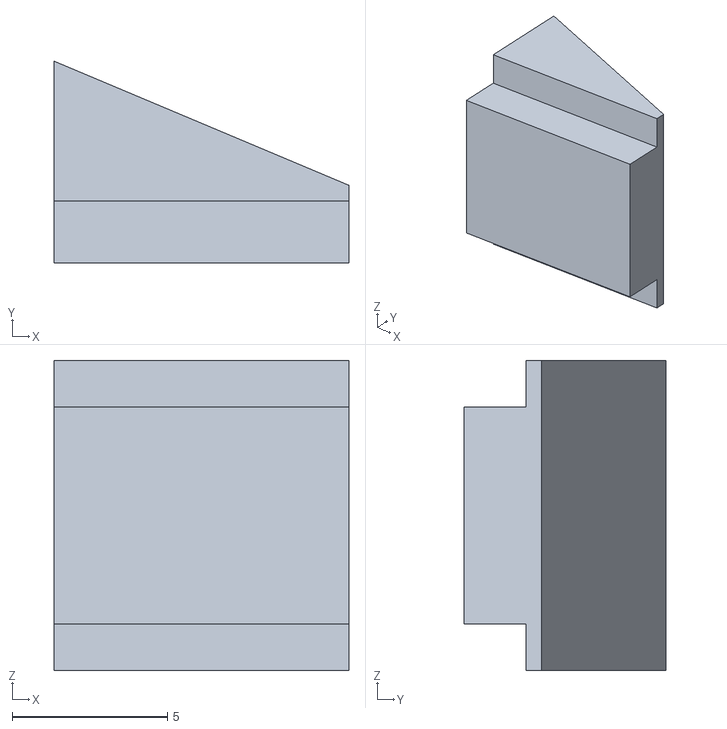
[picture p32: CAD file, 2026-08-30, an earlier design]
Plans3D/NichoirOiseauV1.stl
9.50 x 6.50 x 10.0

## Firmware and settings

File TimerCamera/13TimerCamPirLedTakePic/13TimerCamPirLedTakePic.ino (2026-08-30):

#include <WiFi.h>
#include <PubSubClient.h>

#include "esp_camera.h"
#include "soc/soc.h"
#include "soc/rtc_cntl_reg.h"

#include "M5TimerCAM.h"

#include <WiFiManager.h> // https://github.com/tzapu/WiFiManager

// ===== CONFIGURATION WiFi =====
//const char* ssid = "Asus2.4Max";
//const char* password = "2025ProjetSmarttt";

// ===== CONFIGURATION MQTT =====
const char* mqtt_server = "192.168.1.168";  // IP du Raspberry Pi
const int mqtt_port = 1883;
const char* mqtt_topic_image = "nichoir/camera/image";
const char* mqtt_topic_metadata = "nichoir/camera/metadata";
const char* mqtt_client_id = "M5TimerCAM";

// ===== PINS CAMÉRA (M5Stack TimerCAM) =====
#define PWDN_GPIO_NUM -1
#define RESET_GPIO_NUM 15
#define XCLK_GPIO_NUM 27
#define SIOD_GPIO_NUM 25
#define SIOC_GPIO_NUM 23
#define Y9_GPIO_NUM 19
#define Y8_GPIO_NUM 36
#define Y7_GPIO_NUM 18
#define Y6_GPIO_NUM 39
#define Y5_GPIO_NUM 5
#define Y4_GPIO_NUM 34
#define Y3_GPIO_NUM 35
#define Y2_GPIO_NUM 32
#define VSYNC_GPIO_NUM 22
#define HREF_GPIO_NUM 26
#define PCLK_GPIO_NUM 21

// ===== VARIABLES GLOBALES =====
WiFiClient espClient;
PubSubClient mqttClient(espClient);

int photoCounter = 0;
unsigned long lastPhotoTime = 0;
const unsigned long PHOTO_INTERVAL = 60000; // 1 minute
const int BOARD_PIRPIN = 4;  //SDA/gpio4
const int BOARD_LEDPIN = 13; //SCL/gpio13


void setup() {
    
    Serial.begin(115200);
    Serial.println("\n--- Démarrage M5Stack TimerCAM (MQTT) ---");

    // Désactiver le brownout detector
    WRITE_PERI_REG(RTC_CNTL_BROWN_OUT_REG, 0);

    // LED interne
    pinMode(2, OUTPUT);
    digitalWrite(2, LOW);

    //PIR et LED sur la board de détection du nichoir
    pinMode(BOARD_PIRPIN, INPUT);
    pinMode(BOARD_LEDPIN, OUTPUT);

    // Configuration de la caméra
    camera_config_t config;
    config.ledc_channel = LEDC_CHANNEL_0;
    config.ledc_timer = LEDC_TIMER_0;
    config.pin_d0 = Y2_GPIO_NUM;
    config.pin_d1 = Y3_GPIO_NUM;
    config.pin_d2 = Y4_GPIO_NUM;
    config.pin_d3 = Y5_GPIO_NUM;
    config.pin_d4 = Y6_GPIO_NUM;
    config.pin_d5 = Y7_GPIO_NUM;
    config.pin_d6 = Y8_GPIO_NUM;
    config.pin_d7 = Y9_GPIO_NUM;
    config.pin_xclk = XCLK_GPIO_NUM;
    config.pin_pclk = PCLK_GPIO_NUM;
    config.pin_vsync = VSYNC_GPIO_NUM;
    config.pin_href = HREF_GPIO_NUM;
    config.pin_sscb_sda = SIOD_GPIO_NUM;
    config.pin_sscb_scl = SIOC_GPIO_NUM;
    config.pin_pwdn = PWDN_GPIO_NUM;
    config.pin_reset = RESET_GPIO_NUM;
    config.xclk_freq_hz = 20000000;
    config.pixel_format = PIXFORMAT_JPEG;

    if(psramFound()){
        config.frame_size = FRAMESIZE_SVGA; // 800x600
        config.jpeg_quality = 12;
        config.fb_count = 2;
        Serial.println("PSRAM détectée - Haute qualité");
    } else {
        config.frame_size = FRAMESIZE_VGA; // 640x480
        config.jpeg_quality = 15;
        config.fb_count = 1;
        Serial.println("Pas de PSRAM - Qualité standard");
    }

    // Initialisation de la caméra
    esp_err_t err = esp_camera_init(&config);
    if (err != ESP_OK) {
        Serial.printf("❌ Erreur caméra: 0x%x\n", err);
        ESP.restart();
    }
    Serial.println("✅ Caméra initialisée");

    //Connexion WiFi
    connectWiFi();

    // INITIALISATION TIMER CAM (OBLIGATOIRE)
    TimerCAM.begin();
    Serial.println("TimerCAM initialisé");
    getBatteryLevel();

    // Configuration MQTT
    mqttClient.setServer(mqtt_server, mqtt_port);
    mqttClient.setBufferSize(40000); // Augmenter la taille du buffer pour les images

    // Connexion MQTT
    connectMQTT();

    Serial.println("--- Système prêt - Capture automatique toutes les minutes ---");

    // Première photo au démarrage
    delay(2000);
    Serial.println("\n📸 Capture de la première photo...");
    captureAndSendPhoto();
    lastPhotoTime = millis();

}

void loop() {
    // Maintenir la connexion MQTT
    if (!mqttClient.connected()) {
        connectMQTT();
    }
    mqttClient.loop();

    // Vérifier si 1 minute s'est écoulée pour envoyer une Photo
    unsigned long currentTime = millis();

    if (currentTime - lastPhotoTime >= PHOTO_INTERVAL) {
        Serial.println("\n⏰ 1 minute écoulée - Capture automatique");

        if(captureAndSendPhoto()) {
            photoCounter++;
            Serial.printf("✅ Photo #%d envoyée avec succès\n", photoCounter);
            Serial.printf("⏳ Prochaine photo dans 1 minute...\n");
        } else {
            Serial.println("❌ Échec de l'envoi - Nouvelle tentative dans 1 minute");
        }

        lastPhotoTime = currentTime;
    }

    //Vérifier si le PIR détecte, allumer la LED et envoyer une Photo
    //PIR: SDA G4   et   LED: SCL G13
    int pirState = digitalRead(BOARD_PIRPIN);

    if(pirState == HIGH) {
      Serial.println("Détection de mouvement: Capture de photo et flash");
      digitalWrite(BOARD_LEDPIN, HIGH);    //Led On

      if(captureAndSendPhoto()) {
        photoCounter++;
        Serial.printf("✅ Photo #%d envoyée avec succès\n", photoCounter);
        Serial.println("Prochaine photo dans 1 détection de mouvement...\n");
      } else {
        Serial.println("❌ Échec de l'envoi - Nouvelle tentative dans 1 instant");
      }

    } else {
      digitalWrite(BOARD_LEDPIN, LOW);    //Led Off
    }


    delay(100);
}

void connectWiFi() {
    //WiFiManager, Local intialization. Once its business is done, there is no need to keep it around
    WiFiManager wm;
    // WiFi.mode(WIFI_STA); // explicitly set mode, esp defaults to STA+AP
    
    // Test avec un reset ssid et mdp save en NVS précédents
    //wm.resetSettings();

    // Automatically connect using saved credentials,
    // if connection fails, it starts an access point with the specified name ( "AutoConnectAP"),
    // if empty will auto generate SSID, if password is blank it will be anonymous AP (wm.autoConnect())
    // then goes into a blocking loop awaiting configuration and will return success result

    bool res;
    // res = wm.autoConnect(); // auto generated AP name from chipid
    // res = wm.autoConnect("AutoConnectAP"); // anonymous ap
    res = wm.autoConnect("NichoirMaxMod","password"); // password protected ap

    if(!res) {
        Serial.println("WifiManager Failed to connect\n");
        ESP.restart();
    } else {
        //Wifi Connecté   
        Serial.println("WifiManager connected\n");
        Serial.print("Adresse IP: ");
        Serial.println(WiFi.localIP());
    }
}


void connectMQTT() {
  while (!mqttClient.connected()) {
    Serial.print("Connexion MQTT...");
    
    if (mqttClient.connect(mqtt_client_id)) {
      Serial.println("✅ MQTT connecté");
    } else {
      Serial.print("❌ Échec, code erreur: ");
      Serial.print(mqttClient.state());
      Serial.println(" - Nouvelle tentative dans 5s");
      delay(5000);
    }
  }
}

bool captureAndSendPhoto() {
  // Vérification WiFi
  if(WiFi.status() != WL_CONNECTED) {
    Serial.println("❌ WiFi déconnecté");
    connectWiFi();
    return false;
  }

  // Vérification MQTT
  if(!mqttClient.connected()) {
    connectMQTT();
    return false;
  }

  // Allumer la LED
  digitalWrite(2, HIGH);

  // Capture de l'image
  camera_fb_t * fb = esp_camera_fb_get();
  if(!fb) {
    Serial.println("❌ Échec capture caméra");
    digitalWrite(2, LOW);
    return false;
  }

  Serial.printf("📸 Image capturée: %d octets\n", fb->len);

  // Envoi des métadonnées
  String metadata = "{";
  metadata += "\"photo_id\":" + String(photoCounter) + ",";
  metadata += "\"timestamp\":" + String(millis()) + ",";
  metadata += "\"size\":" + String(fb->len) + ",";
  metadata += "\"battery\":" + String(getBatteryLevel()) + ",";
  metadata += "\"source\":\"AUTO\"";
  metadata += "}";
  
  mqttClient.publish(mqtt_topic_metadata, metadata.c_str());
  Serial.println("📤 Métadonnées envoyées");

  // Envoi de l'image en plusieurs morceaux si nécessaire
  bool success = sendImageMQTT(fb);

  // Libération de la mémoire
  esp_camera_fb_return(fb);
  digitalWrite(2, LOW);

  return success;
}

bool sendImageMQTT(camera_fb_t * fb) {
  const int CHUNK_SIZE = 8192; // 8KB par paquet
  int totalChunks = (fb->len + CHUNK_SIZE - 1) / CHUNK_SIZE;
  
  Serial.printf("📤 Envoi de l'image en %d morceaux...\n", totalChunks);

  for(int i = 0; i < totalChunks; i++) {
    int start = i * CHUNK_SIZE;
    int remaining = fb->len - start;
    int chunkSize = (remaining < CHUNK_SIZE) ? remaining : CHUNK_SIZE;
    
    // Publier le morceau
    bool published = mqttClient.publish(mqtt_topic_image, 
                                        fb->buf + start, 
                                        chunkSize, 
                                        false);
    
    if(!published) {
      Serial.printf("❌ Échec envoi morceau %d/%d\n", i+1, totalChunks);
      return false;
    }
    
    Serial.printf("✓ Morceau %d/%d envoyé\n", i+1, totalChunks);
    delay(50); // Petit délai entre les morceaux
  }
  
  // Signal de fin d'image
  mqttClient.publish(mqtt_topic_metadata, "{\"status\":\"complete\"}");
  Serial.println("✅ Image complète envoyée");
  
  return true;
}

int getBatteryLevel() {
    Serial.printf("Bat Voltage: %dmv\r\n", TimerCAM.Power.getBatteryVoltage());
    Serial.printf("Bat Level: %d%%\r\n", TimerCAM.Power.getBatteryLevel());

    String volt = String(TimerCAM.Power.getBatteryVoltage());
    String levl = String(TimerCAM.Power.getBatteryLevel());
    mqttClient.publish("Volt", volt.c_str());
    mqttClient.publish("Levl", levl.c_str());
    
    return TimerCAM.Power.getBatteryLevel(); //int envoyé vers mqtt
}

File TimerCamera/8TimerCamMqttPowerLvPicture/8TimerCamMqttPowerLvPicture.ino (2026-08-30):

#include "M5TimerCAM.h"  

#include <WiFi.h>
#include <PubSubClient.h>

#include <base64.h>

// ---------- WIFI ----------
const char* ssid     = "Asus2.4Max";
const char* password = "2025ProjetSmarttt";

// ---------- MQTT ----------
const char* mqtt_server = "192.168.1.168";
WiFiClient espClient;
PubSubClient client(espClient);

// ---------- WIFI CONNECT ----------
void setupWiFi() {
  Serial.print("Connecting to WiFi");
  WiFi.begin(ssid, password);

  while (WiFi.status() != WL_CONNECTED) {
    delay(500);
    Serial.print(".");
  }

  Serial.println("\nWiFi Connected!");
  Serial.print("IP: ");
  Serial.println(WiFi.localIP());
}

// ---------- MQTT RECONNECT ----------
void reconnectMQTT() {
  while (!client.connected()) {
    Serial.print("Connecting to MQTT...");
    if (client.connect("TimerCamTestClient")) {   // clientID
      Serial.println("connected!");
    } else {
      Serial.print("failed rc=");
      Serial.print(client.state());
      Serial.println(" trying again in 2s");
      delay(2000);
    }
  }
}

// -------------- My camera init --------------
void myCamInit(){
   if (!TimerCAM.Camera.begin()) {
      Serial.println("Camera Init Fail");
      return;
  }
  Serial.println("Camera Init Success");

  TimerCAM.Camera.sensor->set_pixformat(TimerCAM.Camera.sensor, PIXFORMAT_JPEG);
  // 2MP Sensor
  TimerCAM.Camera.sensor->set_framesize(TimerCAM.Camera.sensor, FRAMESIZE_UXGA);
  // 3MP Sensor
  // TimerCAM.Camera.sensor->set_framesize(TimerCAM.Camera.sensor, FRAMESIZE_QXGA);

  TimerCAM.Camera.sensor->set_vflip(TimerCAM.Camera.sensor, 1);
  TimerCAM.Camera.sensor->set_hmirror(TimerCAM.Camera.sensor, 0);
}

// ------------ My Picture Function------------
void TakePictureFct(){
  if (TimerCAM.Camera.get()) {

    size_t len = TimerCAM.Camera.fb->len;
    String myLen = String(TimerCAM.Camera.fb->len);
    uint8_t* buf = TimerCAM.Camera.fb->buf;

    Serial.printf("Captured JPG: %d bytes\n", len);

    // ----------- PUBLISH PICTURE -----------
    // IMPORTANT: binary-safe MQTT publish
    bool ok = client.publish("picture", buf, len);
    
    String encodedImg = base64::encode(buf,len);
    bool okBase64 = client.publish("picture64", encodedImg.c_str());
    client.publish("picsize", myLen.c_str());

    if (ok)
        Serial.println("MQTT: Picture sent!");
    else
        Serial.println("MQTT: Failed to send picture!");

    if (okBase64)
        Serial.println("MQTT: Picture64 sent!");
    else
        Serial.println("MQTT: Failed to send picture64!");

    // free frame buffer
    TimerCAM.Camera.free();
  }
}

// ============================================================
//  SETUP
// ============================================================
void setup() {
  Serial.begin(115200);

  TimerCAM.begin(true);
  myCamInit();

  setupWiFi();

  client.setServer(mqtt_server, 1883);
  reconnectMQTT();

 
}

// ============================================================
//  LOOP
// ============================================================
unsigned long lastMsg = 0;

void loop() {
  if (!client.connected()) reconnectMQTT();
  client.loop();

  unsigned long now = millis();
  if (now - lastMsg > 5000) {
    lastMsg = now;

    //Send Battery Voltage and Level
    Serial.printf("Bat Voltage: %dmv\r\n", TimerCAM.Power.getBatteryVoltage());
    Serial.printf("Bat Level: %d%%\r\n", TimerCAM.Power.getBatteryLevel());

    String volt = String(TimerCAM.Power.getBatteryVoltage());
    String levl = String(TimerCAM.Power.getBatteryLevel());

    client.publish("Volt", volt.c_str());
    client.publish("Levl", levl.c_str());
    Serial.println("Published: Voltage and Level");
    TakePictureFct();
  }
}

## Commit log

2026-08-31 Add files via upload
    Retrait de la boucle loop() et gestion améliorée des wakeup reason
2026-09-01 Add files via upload
    Amélioration de la fonction goToSleep(), désactivation des modules wifi et mqtt avant l'activation de chaque deep sleep
2026-09-02 Add files via upload
    Désinit complete de la camera avant de lancer le DeepSleep
2026-09-03 Add files via upload
    Retrait de lastPhotoTime et photoCounter, penser à retirer deux publish mqtt dans la fct getBatteryLevel()
2026-09-04 Add files via upload
    Retrait des mqttClient.Publish de trop dans la fct getBatteryLevel()
2026-09-05 Add files via upload
    Réduction de la qualité camera;
    Séparation de ConnectWifi() en 2 fcts BeginWifi() pour ne pas recréer de point d'acces inutilement après le premier boot;
    Verification de tous les wifiBegin/Connect ainsi que les MqttConnect afin de réduire la consommation;
    PhotoCounter RTC ajouté;
    CaptureAndSendPhoto() ajout de la source dans les metadata;
2026-09-06 Add files via upload
    Retrait d'un GetBatteryLevel() inutile,
    Wakeup 1/j pour la batterie
    SchematicTimerCam
    Consommation batterie PIR et TimerCam
